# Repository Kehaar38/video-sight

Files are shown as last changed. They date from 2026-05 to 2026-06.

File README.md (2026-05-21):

# VIDEO SIGHT

VIDEO SIGHT is a compact digital sight prototype built around Seeed Studio XIAO ESP32-S3 Sense.

The project goal is a low-latency, approximately 1x-feeling video sight with camera input, LCD display, IMU-assisted attitude information, and a lightweight ballistic overlay for airsoft use.

## Current hardware direction

- Main MCU: Seeed Studio XIAO ESP32-S3 Sense
- Camera: XIAO ESP32-S3 Sense camera module
- Display: Waveshare 1.83 inch LCD Rev2 / ST7789P / 240x284
- IMU: BNO055 module
- UI sub-MCU: ATtiny1616
- Battery: protected 18650 cell
- microSD CS: GPIO21 on XIAO ESP32-S3 Sense
- Peripheral power switch: TPS22919, controlled by D6/GPIO43
- Reverse polarity protection: AO3401A P-MOSFET

## Repository layout

```text
docs/
  hardware/
    parts_and_pinout.md
    power/
    reviews/
hardware/
  kicad/
firmware/
  esp32s3/
  attiny1616/
```

## Status

Early hardware design. The current focus is the power path and first test PCB.

See:

- `docs/hardware/parts_and_pinout.md`
- `docs/hardware/power/power_bom.md`
- `docs/hardware/power/power_design_notes.md`
- `docs/hardware/reviews/2026-05-20_power_schematic_review.md`

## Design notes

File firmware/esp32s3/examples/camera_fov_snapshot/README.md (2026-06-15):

# camera_fov_snapshot

XIAO ESP32S3 Sense付属OV3660カメラのFOV確認用PlatformIO例です。

## 目的

- LCDへライブビューを表示する。
- Wakeボタン(D0/GPIO1)で、カメラ取得フレームをmicroSDへBMP保存する。
- 既知寸法物を撮影し、保存BMP上のピクセル数からカメラFOVを測定する。

## 現在の確認済み設定

```text
Camera: OV3660 / RGB565
Frame: XGA 1024x768
LCD: Waveshare 1.83inch Rev2 / ST7789P / 240x284 / rotation 0
LCD live crop: center 101x118 -> 240x284
SD CS: GPIO21
Wake button: D0/GPIO1 active LOW
```

XGA設定は実機で映像表示できた設定です。QXGA/UXGA RGB565はビルドは通りましたが、実機では `capture failed` になりました。

## FOV測定メモ

VGA保存BMPでの実測値:

```text
測定対象: 150 x 300mmの差し金
距離: カメラから約1000mm
保存画像: 640 x 480px
測定対象の画像上サイズ: 48 x 95px

カメラ生FOV:
  水平: 約90.00°
  垂直: 約74.32°
```

XGA設定では、VGAより高いピクセル密度で再測定できる可能性があります。センサー側クロップ/ROI取得が成功した場合は、その方式をこのFOV測定例にも応用し、LCD表示範囲または指定ROIだけを保存する方向を検討します。

## 使い方

```bash
cd firmware/esp32s3/examples/camera_fov_snapshot
pio run
pio run -t upload
pio device monitor
```

microSDの `/fov/` 配下にBMPが保存されます。

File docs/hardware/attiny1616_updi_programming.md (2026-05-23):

# ATtiny1616 UPDI programming power notes

## Question

A simple 3-pin UPDI header was considered:

```text
1: PERIPH_3V3
2: GND
3: PA0 / UPDI
```

Concern: if a programmer supplies VCC on pin 1, the programmer will energize the entire `PERIPH_3V3` rail, including other peripherals and the TPS22919 OUT side.

## Judgment

That concern is valid.

Do not treat the UPDI header VCC pin as an unconditional external power input for the ATtiny1616 while it is directly tied to `PERIPH_3V3`.

If the programmer drives VCC into this pin, it can power:

- ATtiny1616,
- BNO055 module,
- LCD VCC side,
- any pull-ups/loads on `PERIPH_3V3`,
- TPS22919 VOUT side.

This may also create unwanted reverse/back-power conditions toward the TPS22919 input side depending on the load-switch behavior and surrounding circuitry.

## Recommended approaches

### Preferred: target-powered UPDI header

Use the header VCC pin as target voltage reference/sense only, not as programmer-supplied power.

```text
UPDI header:
  VREF = PERIPH_3V3
  GND
  UPDI = PA0
```

Programming procedure:

1. Power the board normally.
2. Ensure `PERIPH_3V3` is ON.
3. Programmer uses VREF to set 3.3V signal level.
4. Programmer does not source power into VREF.

This is cleanest for in-circuit programming.

### Add a manual PERIPH_EN force option

Because ATtiny1616 is behind TPS22919, it is not powered unless `PERIPH_3V3` is enabled. Add a temporary/jumper option for bring-up:

```text
PERIPH_EN_FORCE:
  PERIPH_EN -> 3.3V through jumper or 10k
```

This lets the rail turn on during programming even before firmware controls GPIO41 correctly.

### If programmer-powered standalone programming is needed

Add an isolation jumper for ATtiny VCC:

```text
PERIPH_3V3 -- JP_ATtiny_VCC -- ATtiny VCC
UPDI_VCC   -- optional programmer VCC input
```

Normal use:

```text
JP_ATtiny_VCC closed
UPDI_VCC not used as power
```

Standalone programming:

```text
JP_ATtiny_VCC open
programmer powers only ATtiny VCC island
```

This is more flexible but adds complexity and another jumper to manage.

## Small implementation notes

- Add a 470Ω〜1kΩ series resistor on the UPDI signal if desired for protection/debug friendliness.
- Label the header clearly: `VREF / GND / UPDI`, not just `VCC / GND / UPDI`, if the pin is not meant to power the rail.
- If using a programmer that always sources VCC, do not connect its VCC pin to `PERIPH_3V3` unless intentionally powering the whole peripheral rail.

## Current recommendation for VIDEO SIGHT test board

Use target-powered UPDI:

```text
J_UPDI:
  1: PERIPH_3V3 as VREF only
  2: GND
  3: PA0/UPDI
```

Also add a jumper/test option to force `PERIPH_EN` high for bring-up/programming.

If later standalone ATtiny programming becomes necessary, add an ATtiny VCC isolation jumper in the second board revision.

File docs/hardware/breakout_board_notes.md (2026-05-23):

# XIAO breakout board notes

## Purpose

Use a small breakout/interposer board and cable between the XIAO ESP32-S3 Sense and the VIDEO SIGHT test board so the XIAO/camera position can be adjusted inside a temporary enclosure.

## BAT- and GND

For the XIAO ESP32-S3 Sense battery connector, `BAT-` should be treated as board `GND`.

Design implication:

- `BAT-` and `GND` can be one schematic net.
- A connector does not need separate logical nets for `BAT-` and `GND`.
- Do not use `BAT-` as an isolated low-side current-sense or low-side switch node; it is not isolated from system ground on the XIAO.

## Cable recommendation

Even though `BAT-` and `GND` are the same logical net, the cable should provide enough ground conductors for return current and signal integrity.

Recommended for the XIAO breakout cable:

- At least one ground conductor paired with the battery/supply path.
- Additional GND pins near SPI/I2C/high-speed/control signal groups if connector pin count allows.
- Prefer not to rely on a single thin GND wire for all XIAO current plus SPI/LCD return current.

Use a single `GND` net in KiCad, but expose multiple physical GND pins on the breakout connector if practical.

## Measurement note

Keep current measurement on the high side as already planned:

```text
18650+ -> SW -> AO3401A -> JP_BAT_CURRENT -> XIAO BAT+
```

Avoid low-side current measurement between `BAT-` and `GND`, because those are common on the XIAO side.

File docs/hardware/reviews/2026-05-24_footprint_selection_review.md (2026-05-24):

# Footprint selection review 2026-05-24

## Scope

Reviewed pushed commit `3e11275` after footprint selection for the VIDEO SIGHT test-board schematic.

KiCad CLI is not available in this environment, so this review is based on the `.kicad_sch` text and project files rather than a full ERC/DRC run.

## Overall judgment

The footprint selection is generally appropriate for a hand-assembled first test board.

Good choices:

- 0805 hand-solder footprints for resistors and small capacitors.
- Large THT test pads for all test points.
- Pin headers for LCD, UPDI, ATtiny breakout, input device, and current/VCC jumpers.
- Keyed IDC 2x10 header for the XIAO breakout cable.
- R7/R8 are now marked DNP in KiCad, matching the schematic note.
- AO3401A uses standard SOT-23 with pin mapping already checked as `1=G, 2=S, 3=D`.

## Selected footprints observed

```text
R1-R8: 0805 hand-solder resistors
C1/C2/C5/C6/C7/C8/C9: 0805 hand-solder capacitors
C3/C4: custom electrolytic/tantalum-style footprint @自分用:CAP_FN_B_PAN
Q1: Package_TO_SOT_SMD:SOT-23
U1: custom @自分用:DCK0006A_L
U2: SOIC-20W 7.5x12.8mm P1.27mm
J1: JST-XH 2-pin vertical
J2: IDC 2x10 P2.54 vertical
J3/J5/J6/J7/J8/JP1/JP2: 2.54mm pin headers
J4: DIP-8 W7.62mm socket footprint for the BNO055 module
SW1: DIP slide switch footprint
SW2-SW5: 6mm THT push buttons
SW6: Alps EC12E vertical encoder
TP1-TP16: THT pad D1.5mm Drill0.7mm
```

## Things that look good

### DNP handling

R7/R8 are now `dnp=yes` in the schematic file. This matches the intended policy:

```text
R7/R8 optional I2C pull-ups
Default: DNP
Populate only if module pull-ups are insufficient
```

### Test points

The selected footprint:

```text
TestPoint:TestPoint_THTPad_D1.5mm_Drill0.7mm
```

is a good default for this test board. It is easy to probe and can accept temporary wires.

### Passive size

0805 hand-solder footprints are a good choice for manual assembly and rework. They are larger than necessary electrically, but well suited for a test board.

### ATtiny package

The SOIC-20W footprint is a friendly choice for hand soldering and recovery compared with smaller packages.

## Items to verify before PCB/order

### 1. Custom footprints must be committed or replaced

The schematic references custom footprint libraries:

```text
@自分用:CAP_FN_B_PAN
@自分用:DCK0006A_L
```

No project `fp-lib-table` or `.pretty` directory was found in the repository. If those footprints exist only in the local KiCad user library, another machine or CI will not be able to resolve them.

Recommended options:

1. Commit the custom `.pretty` library and project `fp-lib-table`, or
2. Replace with standard KiCad footprints if suitable.

This is especially important for `U1` / TPS22919, because the exact DCK/SOT-563-style pad geometry matters.

### 2. TPS22919 footprint/pin mapping

`U1` uses:

```text
@自分用:DCK0006A_L
```

Before layout/order, verify against the TPS22919 datasheet:

- pin 1 location,
- pad numbering,
- package variant DCK,
- thermal/assembly recommendations,
- KiCad symbol pin numbers.

### 3. C3/C4 footprint and polarity

C3/C4 are both `47uF` and use the custom `CAP_FN_B_PAN` footprint.

Check:

- capacitor type: electrolytic, tantalum, polymer, or large MLCC,
- polarity marking if polarized,
- voltage rating,
- physical height/diameter,
- pad spacing and courtyard.

If using polarized capacitors, make polarity very clear on silkscreen.

### 4. BNO055 module socket footprint

`J4` uses:

```text
Package_DIP:DIP-8_W7.62mm_Socket
```

This can work if the module header really matches 2x4, 2.54mm pitch, 7.62mm row spacing. Before PCB order, measure/check the AE-BNO055-BO board header spacing.

A generic `PinSocket_2x04_P2.54mm` footprint may be clearer than a DIP IC socket footprint if the physical part is a module header/socket.

### 5. IDC connector orientation

`J2` uses:

```text
Connector_IDC:IDC-Header_2x10_P2.54mm_Vertical
```

This matches the keyed-cable plan. Still verify in PCB:

- pin 1 mark,
- key notch direction,
- cable exits in the intended direction,
- straight-through cable maps J1 pin N to J2 pin N,
- no mirrored orientation between breakout and test board.

### 6. LCD header mechanical fit

`J3` is a normal 1x08 vertical pin header. Confirm this matches the Waveshare module orientation and whether the module should plug directly, use wires, or use a socket.

### 7. Switch and encoder footprints

The selected footprints are plausible, but they depend heavily on exact parts:

- `SW_PUSH_6mm` for tactile switches,
- `RotaryEncoder_Alps_EC12E_Vertical_H20mm` for encoder,
- DIP slide switch footprint for SW1.

Before ordering, compare to the actual part datasheets or the parts in hand.

## User follow-up decisions

After this review, the following project decisions were noted:

- The custom footprints were downloaded from public sources. The repository is public, but third-party reuse is not a major goal for this project.
- TPS22919, C3/C4, and BNO055 footprints were chosen based on actual parts/modules in hand, so mechanical fit is expected to be acceptable.
- The IDC cable will be obtained before PCB order so the key orientation and straight-through pin mapping can be checked physically.
- The bundled LCD cable terminates in a normal 2.54mm pin socket and can be reversed. For the final build, consider making a custom cable or keyed connection that fixes orientation.

## Custom-footprint policy note

If the downloaded footprints have a license that allows redistribution, committing a project-local `.pretty` library is ideal.

If the license is unclear or redistribution is inconvenient, it is acceptable for this personal/prototype repository to keep them as local KiCad user-library footprints, but then the project is not fully reproducible from Git alone.

For this project, the practical minimum is:

- keep the exact source URL/package name for each custom footprint in a note,
- export Gerbers from the same KiCad environment that has those footprints installed,
- visually inspect the generated Gerber/pads before ordering.

## Summary

Accepted as a test-board footprint baseline:

- 0805 hand-solder passives,
- THT test points,
- pin headers/jumpers,
- SOIC-20W ATtiny,
- SOT-23 AO3401A,
- DNP status for R7/R8.

Main reproducibility caveat:

- custom footprints `@自分用:*` are local unless their source/license allows committing them or they are replaced by standard/library footprints.

Main mechanical checks before PCB order:

- TPS22919 DCK footprint pin mapping,
- BNO055 module row spacing,
- IDC key orientation using the actual cable,
- LCD cable/header orientation or custom keyed cable plan,
- switch/encoder exact part footprints.

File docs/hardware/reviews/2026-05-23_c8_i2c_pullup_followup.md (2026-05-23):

# Schematic review follow-up 2026-05-23: C8 and I2C pull-ups

## Scope

Reviewed pushed update `367950b`:

- moved C8 around the ATtiny1616 VCC jumper,
- added board-side I2C pull-up resistors R7/R8,
- checked the AE-BNO055-BO module documentation image.

## ATtiny1616 C8

C8 is now on the `UPDI_VCC` / ATtiny VCC side of JP2:

```text
PERIPH_3V3 -- JP2 -- UPDI_VCC / ATtiny VCC
                         |
                        C8 0.1uF
                         |
                        GND
```

This is the correct side for the MCU local decoupling capacitor. It will still decouple the ATtiny when JP2 is open and the programmer powers `UPDI_VCC` directly.

## Board-side I2C pull-ups

The added topology is correct:

```text
PERIPH_3V3
  ├─ R7 4.7k -> I2C_SDA
  └─ R8 4.7k -> I2C_SCL
```

Pulling SDA/SCL to `PERIPH_3V3` is the right rail because BNO055 and ATtiny1616 are on the switched peripheral 3.3V domain.

## AE-BNO055-BO module pull-ups

The provided module documentation appears to show pull-up resistors already present on the module:

- parts list: `R1-R5 = RK73B1ETTP103J`, where `103` means 10kΩ,
- schematic: R1/R2 appear associated with the I2C signal lines and the module's 2.8V domain.

So the module may already provide I2C pull-ups, likely around 10kΩ. The board-side 4.7k pull-ups are therefore best treated as optional/DNP until measured or confirmed.

## Electrical implication if both are populated

If the module has 10k pull-ups and the board also installs 4.7k pull-ups, the effective pull-up becomes stronger:

```text
4.7k || 10k ≈ 3.2kΩ
```

That is usually acceptable for a short 3.3V I2C bus.

If the module pull-ups are to 2.8V while the board pull-ups are to 3.3V, the idle level becomes a weighted value, roughly around 3.1V with 10k-to-2.8V and 4.7k-to-3.3V. This is probably still recognized as High by 3.3V devices, but mixing pull-up rails is not as clean as using one defined pull-up rail.

## Recommendation

For the test board:

- Keep R7/R8 footprints.
- Mark R7/R8 as DNP by default, or choose footprints that are easy to leave open/populate later.
- During bring-up, first measure SDA/SCL idle voltage with the BNO055 module installed and R7/R8 unpopulated.
- If idle level/rise time is weak, populate R7/R8.

Suggested schematic note:

```text
R7/R8: optional I2C pull-ups to PERIPH_3V3; DNP if BNO055 module pull-ups are sufficient.
```

## Summary

Accepted:

- C8 placement is now correct.
- R7/R8 topology is correct for board-side optional I2C pull-ups.

Recommended change before layout/BOM:

- Make R7/R8 optional/DNP by default or add a note, because the AE-BNO055-BO module likely already includes 10k I2C pull-ups.

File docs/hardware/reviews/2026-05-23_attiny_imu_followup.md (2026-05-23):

# Schematic review follow-up 2026-05-23: ATtiny UPDI and IMU updates

## Scope

Reviewed pushed updates after:

- adding ATtiny1616 UPDI/programming VCC selection,
- adding the internal-pull-up note for the input devices,
- adding IMU test points,
- marking unused XIAO breakout camera I2C lines as NC.

## ATtiny1616 / UPDI

The jumper-based VCC selection is the right direction.

Current visible intent:

```text
PERIPH_3V3 -- JP2 ATTINY_VCC -- UPDI_VCC / ATtiny VCC
J4:
  pin 1 = UPDI_VCC
  pin 2 = GND
  pin 3 = PA0_UPDI through R6 470Ω
```

This lets the ATtiny be normally powered from `PERIPH_3V3`, while allowing the ATtiny-side VCC node to be separated for programmer-powered work.

### Important check: decoupling capacitor location

In the screenshot, C8 appears to be on the `PERIPH_3V3` side of JP2. If JP2 is open and the programmer powers `UPDI_VCC`, C8 may no longer decouple the ATtiny VCC pin.

Recommendation:

- Put the ATtiny local 0.1µF decoupling capacitor on the ATtiny VCC / `UPDI_VCC` side, as close to U3 VCC/GND as practical.
- If desired, keep an additional capacitor on `PERIPH_3V3`, but the mandatory MCU decoupling should follow the MCU VCC island.

### Labeling recommendation

Add a note near JP2/J4 such as:

```text
Normal: JP2 closed, UPDI_VCC = PERIPH_3V3, programmer VCC as VREF only
Programmer-powered: JP2 open, programmer may power UPDI_VCC only
```

This prevents accidentally powering the whole `PERIPH_3V3` rail from the UPDI programmer.

### UPDI series resistor

R6 = 470Ω on PA0_UPDI is good for a test board. It adds some protection/debug friendliness without being excessive.

### Input pull-up note

The input-device note `ATtiny internal pull-up enabled` is good. The switch/encoder wiring to GND is consistent with firmware-enabled internal pull-ups.

## IMU / BNO055

The IMU update added test points, not I2C pull-ups. The visible support pins are now brought to test points:

```text
TP13 = IMU_2V8
TP14 = GND
TP15 = IMU_INT
TP16 = IMU_RESET
```

This is useful for bring-up.

### I2C pull-ups still remain as a separate future check

Because the IMU change was TP-only, discrete I2C pull-up resistors are still a separate design decision. The screenshot and KiCad text currently do not show board-side pull-up resistors such as:

```text
I2C_SDA -> 4.7k -> PERIPH_3V3
I2C_SCL -> 4.7k -> PERIPH_3V3
```

If the intended pull-ups are on the BNO055 module, that may be acceptable. If the intent was to add optional board-side pull-up footprints, they do not appear to be present in the pushed schematic yet.

Recommendation for test board:

- Add optional/DNP board-side pull-up footprints on SDA/SCL to `PERIPH_3V3`, or
- Add a note that the pull-ups are supplied by the BNO055 module.

### IMU_2V8 caution

Keeping `IMU_2V8` as a test point is fine. Treat it as a module-side output/reference unless the exact module documentation says otherwise. Do not connect it to `PERIPH_3V3`.

## CAM_SDA / CAM_SCL

Marking unused `CAM_SDA` and `CAM_SCL` as NC is good if they are not routed to test points or used on the test board.

## Summary

Accepted:

- VCC jumper approach for ATtiny programming,
- 470Ω UPDI series resistor,
- internal pull-up note for input devices,
- IMU support/test points,
- CAM_SDA/CAM_SCL NC marking.

Still separate future check:

- optional I2C pull-up resistors or a note that module-side pull-ups are used.

1. Move/add the ATtiny 0.1µF decoupling capacitor to the `UPDI_VCC` / ATtiny VCC side of JP2.
2. Add a clear JP2/J4 programming-power note.
3. Confirm whether I2C pull-ups are module-provided or add optional DNP 4.7k pull-ups to `PERIPH_3V3`.

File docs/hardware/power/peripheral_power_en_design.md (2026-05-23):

# VIDEO SIGHT 周辺電源EN案

## 対象

DeepSleep時に電源を落とす対象は、XIAO 3V3ピンから供給予定だった外部周辺のみ。

- Waveshare 1.83inch LCD Rev2 VCC
- BNO055 VCC
- ATtiny1616 VCC

XIAO本体、Senseカメラ、microSD等の基板内蔵系はこのENでは制御しない。

## 現在の方針

- `PERIPH_3V3` はTPS22919ロードスイッチで作る。
- `PERIPH_EN` は GPIO41 / D12 背面パッドから制御する。
- D6 / GPIO43 は `LCD_BL` に戻し、LCDバックライトPWM調光用として使う。
- ENには100kΩ程度のプルダウンを入れ、起動直後/DeepSleep中/リセット中に周辺電源がOFFになるようにする。

## 評価

利点:

- D6/GPIO43をLCD_BLに戻せるため、バックライト電流と輝度を実測・調整できる。
- LCD/IMU/サブMCUをDeepSleep時に確実に落とせる。
- GPIOがHi-ZになってもプルダウンでOFFにできる。
- 周辺電源制御が1本にまとまり、ソフト電源ボタン設計と相性がよい。

注意点:

- GPIO41/D12はXIAO背面パッド側なので、ブレイクアウトボードで確実に引き出す必要がある。
- XIAOのカメラシールド/マイク用ジャンパーとの関係を確認する。
- 周辺電源OFF中にSPI/I2C/GPIOからバックパワーしないよう、DeepSleep前に信号線をLow/Hi-Zへ落とす。
- ATtiny1616も電源OFFになるため、UIサブMCUでWakeする構成ではなく、XIAO直結Wakeボタンで復帰する。

## 推奨回路イメージ

```text
XIAO_3V3
  ↓
TPS22919 Load Switch
  EN ← GPIO41 / D12 pad + pulldown
  ↓
PERIPH_3V3
  ├─ LCD VCC
  ├─ BNO055 VCC
  └─ ATtiny1616 VCC

D6 / GPIO43
  ↓
LCD_BL
```

## 追加確認

- ロードスイッチの入力電圧範囲: 3.3V対応。
- 出力電流: LCD/IMU/ATtinyの合計電流に十分余裕。
- R_on: 電圧降下が小さいもの。
- EN閾値: ESP32の3.3V GPIOで確実にON/OFFできる。
- OFF時リーク電流: DeepSleep目標に合う。
- 起動順: 起動後にGPIO41を出力Low→周辺初期化直前にHigh。

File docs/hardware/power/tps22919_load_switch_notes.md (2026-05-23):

# TPS22919 検討メモ

## 用途

VIDEO SIGHT の `PERIPH_3V3` 生成用ロードスイッチ候補。

```text
XIAO 3V3
  → TPS22919
  → PERIPH_3V3
      - LCD VCC
      - BNO055 VCC
      - ATtiny1616 VCC
```

LCD_BLはD6/GPIO43で別制御する。

ENは GPIO41/D12 pad から制御し、ENにプルダウンを入れて起動直後/DeepSleep中はOFFへ倒す。

## 確認した仕様

TI製品ページより:

- 品名: TPS22919
- 機能: 5.5-V, 1.5-A, 90-mΩ load switch with adjustable output discharge
- Vin: 1.6V〜5.5V
- Imax: 1.5A
- Ron typ: 90mΩ
- Iq typ: 8µA
- Shutdown current typ: 0.002µA
- Features: Inrush current control, Quick output discharge, Short circuit protection, Thermal shutdown
- Soft start: Fixed rise time
- Package image: 6-pin DCK

DCKはTIの小型リード付きSMDパッケージ系で、QFN/BGAではない。手はんだは可能だがかなり小さい。

## 電圧降下・発熱目安

Ron=90mΩとして:

- 0.1A: 9mV / 0.9mW
- 0.2A: 18mV / 3.6mW
- 0.3A: 27mV / 8.1mW
- 0.5A: 45mV / 22.5mW
- 1.0A: 90mV / 90mW
- 1.5A: 135mV / 202.5mW

VIDEO SIGHTの周辺電流が数十〜数百mAなら十分余裕がある。

## 判断

TPS22919はVIDEO SIGHTの周辺電源スイッチとして使える。保護機能と低Ron、低シャットダウン電流があり、3.3Vロードスイッチ用途に合う。

注意:

- パッケージDCKはリード付きだが小さい。試作ではDCK→DIP変換基板等を使うとよい。
- ENピンには外付けプルダウンを入れる。
- Quick output discharge付きなので、OFF時にPERIPH_3V3が速く落ちる。LCD/IMU/ATtiny用途には都合が良い。
- 出力側大容量コンデンサやバックライト突入電流はデータシート推奨に従って確認する。

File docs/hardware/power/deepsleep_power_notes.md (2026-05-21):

# XIAO ESP32-S3 Sense DeepSleep と周辺電源メモ

## 調査元

- Seeed Studio Wiki: `XIAO ESP32S3 Sense Sleep Modes`
- Espressif ESP-IDF Programming Guide: ESP32-S3 Sleep Modes
- Seeed Studio Wiki: XIAO ESP32-S3 pin multiplexing / 3V3説明

## 結論

- XIAOの3V3端子は、オンボードDCDCレギュレータの出力であり、DeepSleepに入っても自動的に切れるものではないと考える。
- ESP32-S3のDeepSleepでは、CPU、ほとんどのRAM、APB_CLK系のデジタル周辺は電源断/停止する。
- 通常GPIOの出力状態は、DeepSleep中に通常動作時と同じように能動駆動される前提にしない。
- RTC GPIOやGPIO hold機能で一部状態保持は可能だが、VIDEO SIGHTでは「GPIO状態に頼って周辺電源が勝手に落ちる」と考えない方が安全。

## VIDEO SIGHTでの設計判断

- 周辺機器をDeepSleep中に落としたい場合は、3V3直結ではなく、ロードスイッチまたはP-MOSFET高側スイッチ等で周辺電源レールを作る。
- 周辺電源ENは、ESP32が起きている時だけONになる設計にする。
- ESP32がDeepSleepに入りGPIOがHi-Z/未保持になっても、抵抗でENがOFF側へ倒れるようにする。
- 周辺電源OFF中は、SPI/I2C/GPIOからバックパワーしないように、DeepSleep直前に関連GPIOをLowまたはHi-Zへ設定する。
- 物理電源スイッチはバッテリーとXIAO BATを切断する形でよい。この場合、切断中はUSB充電不可。保管/バッテリー交換用の完全OFFとして扱い、使用中の一時停止はDeepSleepに任せる。

## 推奨電源ブロック

```text
保護回路付き18650
  ↓
P-MOSFET逆接保護
  ↓
物理電源スイッチ
  ↓
XIAO BAT
  ↓
XIAO 3V3
  ├─ XIAO本体/カメラ系
  └─ 周辺電源ロードスイッチ
       ├─ LCD VCC / BL系
       ├─ BNO055
       └─ ATtiny1616
```

※ カメラ/Sense拡張基板側の電源がXIAO内部でどう分かれているかは、実機でDeepSleep時電流を測る。

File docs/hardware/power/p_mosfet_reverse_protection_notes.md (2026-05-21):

# VIDEO SIGHT P-MOSFET逆接保護メモ

## 選定条件

1セルLi-ion/18650の入口逆接保護用。

- P-channel MOSFET
- VDS定格: 20V以上あれば十分、30V品なら余裕
- RDS(on): VGS=-2.5Vまたは-4.5Vで低いこと。目安100mΩ以下、できれば70mΩ以下
- ID: 連続1A以上、できれば2〜3A級
- VGS(max): ±12Vまたは±20V。1セルLi-ionでは通常問題なし
- パッケージ: SOT-23等のリード付きSMDが扱いやすい。真のDIP/TO-92品は低RDS品が少ない

## 定番候補

- AO3401A / 互換品
  - P-ch, 30V, SOT-23系。安価で入手性が高く、1セル機器の逆接保護でよく使われる。
  - クローン/互換品が多いので、可能ならメーカー品または信頼できる販売店から買う。
- IRLML6402
  - P-ch, 20V, SOT-23系。ロジックレベル寄りで低電圧用途に使いやすい。
- DMP3098L
  - Diodes Inc.のP-ch, 30V, SOT-23系。メーカー品として選びやすい。
- DMG2305UX等
  - Diodes Inc.の小型P-ch候補。低RDSで入手できる場合は良い。

## 回路案

物理スイッチOFFで完全に電池を切りたいなら、スイッチはできればP-MOSFET前段に置く。

```text
保護回路付き18650 +
  ↓
物理電源スイッチ
  ↓
P-MOSFET drain
P-MOSFET source
  ↓
XIAO BAT+
```

P-MOSFETのゲートはGNDへ高抵抗で落とす。

```text
Gate ─ 1MΩ程度 ─ GND
```

Li-ion 1セルではVGSが最大でも約-4.2Vなので、通常はゲート保護ツェナーは不要。ただし長い配線や静電気が気になるなら保護部品を検討する。

## 向き

P-MOSFETのボディダイオードが、正しい極性で一瞬だけ入力から出力へ流れる向きにする。

一般的には:

```text
Drain  = バッテリー/スイッチ側
Source = XIAO BAT側
Gate   = GNDへ抵抗
```

正接続時はボディダイオード経由でSource側が上がり、その後 VGS<0 になってMOSFETがONする。逆接続時はボディダイオードが遮断方向になり、負荷側を守る。

## 抵抗値

- Gate-GND: 1MΩ程度を推奨。4.2V時の常時消費は約4.2µA。
- 100kΩでも動作は堅いが、物理OFF時にこの抵抗が電池へ残る配置だと約42µAを消費する。
- 物理スイッチをMOSFET前段に置けば、OFF時はこの消費も切れる。

## 決定

VIDEO SIGHTでは `AO3401A` を採用する。Digi-Keyで購入するため、互換品/クローンではなく信頼できるメーカー品として扱う。

実装方針:

- パッケージはSOT-23想定。
- PCBAは使わず自分ではんだ付けする。
- SOT-23程度は手実装可能な前提。
- 基板はユニバーサル基板ではなくKiCadで設計し、JLCPCBへ発注する。
- まずテスト用の大きめ基板、その後に筐体組み込み用の本番基板の2段階で作る。

注意:

- AO3401AのSOT-23フットプリントはメーカー推奨ランドまたはJLCPCBで一般的なSOT-23-3ランドを使う。
- Drain/Source/Gateのピン番号をKiCadシンボルと実データシートで必ず照合する。
- 逆接保護ではDrain=バッテリー/スイッチ側、Source=XIAO BAT側、Gate=GNDへ抵抗の向きで確認する。

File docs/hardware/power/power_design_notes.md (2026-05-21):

# VIDEO SIGHT 電源設計メモ

## 現在の方針

- セル: 保護回路付き18650。
- 充電: XIAO USB-C経由の低速充電と、セル取り外しによる外部充電器充電の両対応。
- 逆接保護: P-MOSFET方式を盛り込む。
- 測定: 電流測定用のジャンパ/テストポイントを設ける。
- 電源スイッチ: 物理スイッチあり。
- LCDバックライト: 初期試作ではGPIO直結。ただしBL電流は実測し、GPIO定格超過や発熱があればMOSFET駆動へ変更。
- バッテリー電圧測定: 抵抗分圧を常時接続。
- DeepSleep: 周辺機器もオフにする方針。

## 追加で確認する項目

1. 電源経路とスイッチ位置
   - 物理スイッチをBAT+側のどこに入れるか。
   - OFF時にUSB-C充電を許すか、完全に切るか。
   - USB-C給電中/充電中/電池駆動中の3状態で意図しない逆流がないか。

2. P-MOSFET逆接保護
   - ソース/ドレイン向きとボディダイオードの向きを確認。
   - ゲート保護抵抗、ゲート-ソース抵抗を入れる。
   - 使用電流でのRds(on)による電圧降下と発熱を確認。
   - 保護回路付き18650の低電圧時でもXIAO BAT入力に必要電圧が残るか確認。

3. LCDバックライトGPIO直結の安全性
   - Waveshare 1.83inch LCD Rev2のBLピン回路を確認。
   - BLピンがLED直結/抵抗入り/トランジスタ入力のどれかを確認。
   - GPIO電流定格を超える場合はN-MOSFET PWMへ変更。

4. 周辺電源OFF方式
   - LCD、BNO055、ATtiny1616、必要ならSDへの電源をどう切るか。
   - ロードスイッチまたはP-MOSFET高側スイッチを使うか。
   - OFF時にSPI/I2C/GPIOから周辺へバックパワーしないよう、信号線状態を定義する。
   - ATtiny1616をDeepSleep中も生かすか、完全OFFにするかを決める。

5. Wake設計
   - D0/GPIO1 WakeボタンはDeepSleep復帰用。
   - 周辺電源OFF中でもWake回路が有効か確認。
   - RTC wake対応ピン/外部ウェイク方式を実装前に確認。

6. バッテリー分圧
   - 抵抗値、ADC入力電圧範囲、常時消費電流を決める。
   - ADC読み取り用に分圧中点へ小容量コンデンサを入れるか検討。
   - 実測で電圧補正係数を持つ。

7. 3V3レール余裕
   - カメラ表示、LCD最大輝度、SDアクセス、IMU動作時の電圧降下と発熱を測る。
   - XIAOの3V3出力公称700mAに対して実使用ピークを確認する。
   - 3V3入力側/周辺側へ47〜100uF程度のバルク容量を置く。

8. USB-C充電中の熱
   - XIAO充電IC、DCDC、LCDバックライト、筐体内温度を確認。
   - 充電しながら使用する場合と、電源OFF充電の場合を分けて測る。

9. テストポイント
   - BAT+、BAT後段、3V3、GND、LCD_BL、I2C SDA/SCL、SPI SCK/MOSI/MISO、周辺電源ENを出す。
   - 電流測定用にBAT経路または3V3周辺電源経路へジャンパを入れる。

10. ヒューズ/安全部品
   - 保護回路付きセルを使うが、試作配線や筐体内短絡に備えてリセッタブルヒューズや細い保護配線も検討する。

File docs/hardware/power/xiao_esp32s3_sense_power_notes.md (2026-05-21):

# XIAO ESP32-S3 Sense 電源・充電メモ

## 調査元

- Seeed Studio Wiki: Getting Started with Seeed Studio XIAO ESP32-S3 Series
- Seeed Studio Wiki: Pin Multiplexing with Seeed Studio XIAO ESP32-S3 (Sense)
- Seeed Studio公開KiCad/PDF: `202003753_XIAO ESP32S3 Sense_v1.5_SCH_260226`
- SGMICRO product pages: SGM40567, SGM6029

## 確認できた構成

- 充電IC: `SGM40567-4.2XG/TR`
  - 1セルLi-ion/Li-poly系のリニア充電IC。
  - 4.2V版。
  - Seeedの仕様表では、XIAO ESP32-S3 Sense系の充電電流は `100mA(Fast) / 0.9mA(Trickle)` と読める。
  - 充電中/完了表示用の `NCHG` ピンがCHARGE LEDへ接続されている。
- 3.3Vレギュレータ: `SGM6029CYG/TR`
  - SGM6029は同期整流降圧DCDC。
  - SGMICROページでは入力1.95V〜5.5V、低消費、0.6A〜1A級ピーク出力電流とされる。
  - XIAO pin multiplexingページでは3V3ピンから `700mA` 取り出し可能と記載。
- BAT端子: `VBAT`ネット。
  - 3.7V Li-ion/Li-polyセル接続想定。

## 保護機能について

- `SGM40567` は充電管理ICであり、データシート/製品ページ上は充電制御、再充電、トリクル/プリチャージ、熱電流制限などの機能を持つ。
- ただし、XIAO Sense回路中に `DW01`, `FS8205` 等の典型的な1セルLi-ion保護IC/保護FETは確認できなかった。
- したがって、XIAO側だけにセル保護を任せる前提は避ける。過放電・過電流・短絡保護付きセルまたは外部保護基板付き18650を使うのが安全。

## VIDEO SIGHTへの設計上の意味

- 18650は保護回路付き、または保護基板付きホルダーを推奨。
- 充電電流は大きくないため、USB-C充電は可能だが高速充電用途ではない。
- 3V3レールは公称700mAまで使えるとされるが、カメラ+LCD+IMU+ATtiny+SDを載せるため、実測で電圧降下と発熱を確認する。
- LCDバックライトはできればMOSFETでPWM駆動し、3V3レールの余裕と発熱を確認する。
- USB給電中の動作・充電同時運用は発熱確認が必要。

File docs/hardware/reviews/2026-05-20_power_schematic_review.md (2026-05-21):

# VIDEO SIGHT schematic review 2026-05-20 power draft

## Reviewed images

- XIAO ESP32-S3 Sense symbol / main power nets
- 18650 + SW + AO3401A reverse protection
- Battery divider
- TPS22919 peripheral load switch

## Findings

### OK: AO3401A reverse protection

Current schematic shows:

```text
18650+ → SW → AO3401A pin3
AO3401A pin2 → +BATT
AO3401A pin1 → 1MΩ → GND
```

This matches the intended direction if the KiCad AO3401A symbol uses common pinout:

- pin1 = Gate
- pin2 = Source
- pin3 = Drain

Action: verify against the exact Digi-Key/AOSMD AO3401A datasheet and footprint before PCB.

### OK: Battery divider

Current schematic:

```text
+BATT → 470kΩ → ADC node → 220kΩ → GND
ADC node → 0.047µF → GND
```

This is good. `+BATT` must mean the protected/switched node after AO3401A, not raw battery.

Calculation:

- 4.2V → about 1.34V at ADC
- divider current at 4.2V → about 6.1µA
- Rth ≈ 150kΩ, C=0.047µF gives τ≈7ms, 5τ≈35ms

### Important: TPS22919 output net name

The TPS22919 output is currently shown with a `+3V3` power symbol. This is dangerous/confusing because KiCad power symbols are global. If any other `+3V3` appears on the unswitched XIAO 3V3 rail, it will short TPS22919 IN and OUT and bypass the load switch.

Action: rename nets:

```text
XIAO 3V3 pin / TPS IN  = XIAO_3V3 or 3V3_RAW
TPS OUT                = PERIPH_3V3
```

Do not use the same global `+3V3` symbol on both sides of TPS22919.

### OK: TPS22919 EN pulldown

`EN → 100kΩ → GND` is good. D6/GPIO43 drives the same EN net.

### QOD / R_QOD

TPS22919 QOD is optional but useful.

Datasheet behavior:

- QOD open: output discharge disabled.
- QOD tied to OUT directly: fastest discharge through internal QOD path, about 24Ω typ internal resistance.
- QOD tied to OUT through external R_QOD: adjustable/slower output discharge.

For VIDEO SIGHT, using QOD is recommended so `PERIPH_3V3` collapses reliably before DeepSleep.

Suggested population options:

- R_QOD = 0Ω: fastest discharge. With about 48µF output capacitance, initial discharge current roughly 3.3V/24Ω ≈ 137mA, τ≈1.2ms.
- R_QOD = 100Ω: gentler, initial roughly 27mA, 5τ≈30ms for 48µF.
- R_QOD = 1kΩ: very gentle, initial roughly 3.2mA, 5τ≈250ms for 48µF.
- DNP/open: disables QOD; not preferred if peripherals need clean power reset.

Recommendation: place R_QOD footprint. For first test, populate 100Ω or 1kΩ. Use 0Ω if fast discharge/reset is needed.

### Missing later, expected

- Current measurement jumper(s)
- Battery holder footprint
- Test points
- PERIPH_3V3 bulk capacitor if not on another sheet
- Local decoupling for LCD/IMU/ATtiny modules

## Summary

No fatal issue in the shown draft, but change TPS22919 OUT from global `+3V3` to a distinct `PERIPH_3V3` net before continuing. Keep R_QOD footprint; it is optional electrically, but useful for controlled shutdown.

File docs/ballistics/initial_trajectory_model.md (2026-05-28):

# 初期弾道予測モデル

## 目的

VIDEO SIGHTの初期弾道予測モデルは、実射精度を最初から追い込むための物理シミュレーターではなく、次の機能を先に成立させるための表示用モデルである。

```text
- 固定値から弾道点を計算できる
- LCDへ弾道点をプロットできる
- IMU由来のpitch/rollで表示が変化する
- ハードウェア、描画、IMU、UIの開発を進められる
```

この段階では、風、地面、yaw、射撃中の姿勢変化、実射補正、回転減衰、揚力/抗力係数の変化は扱わない。

## モデルの考え方

このモデルでは、世界座標を明示的に持たない。弾道は、照準器/カメラに固定された `f/r/u` 座標の中で計算する。

```text
f: forward / カメラ前方 / 銃口方向
r: right   / 画面右方向
u: up      / 画面上方向 / ホップ揚力の基準方向
```

弾道予測は「今の姿勢で撃った場合に、カメラ画面内で弾道点がどこへ出るか」を求めるものとする。

そのため、次のものは考慮しない。

```text
風向き:
  測れないため考慮しない。

地面に対するターゲット位置:
  ターゲットはf方向距離だけで扱う。

射撃中の姿勢変化:
  今時点の姿勢での予測表示のみ扱う。

方位/yawを含む空間位置:
  カメラから覗く世界だけを扱うため考慮しない。

地面:
  地形や設置物により一定の地面を仮定できないため、モデルには入れない。
```

## 初期固定値

初期段階では、弾・銃・空気・ホップ関連の値を固定する。

```text
BB重量: 0.20 g
BB直径: 6.0 mm
初速: 90 m/s
空気密度: 1.225 kg/m^3
抗力係数 C_D: 0.47
マグヌス係数 C_L: 0.038
最大予測距離: 40 m
距離ステップ: 2 m
プロット点数: 21点
ゼロイン距離: 30 m相当
サイト高: 仮値 0.05 m
```

計算用の値:

```text
m   = 0.0002 kg
rBB = 0.003 m
A   = π × rBB²
ρ   = 1.225 kg/m^3
Cd  = 0.47
Cl  = 0.038
g   = 9.80665 m/s^2
v0  = 90.0 m/s
```

断面積:

```text
A = π × 0.003²
  ≒ 2.8274e-5 m²
```

抗力・揚力用の定数:

```text
K_drag = 0.5 × ρ × A × Cd / m
K_lift = 0.5 × ρ × A × Cl / m
```

上記固定値では:

```text
K_drag ≒ 0.04070
K_lift ≒ 0.00329
```

## IMUから使う値

初期段階では、IMUから次の2値だけを使う。

```text
pitch = θ
roll  = φ
```

単位はラジアンとする。

```text
pitch θ > 0:
  銃口を上へ向ける。

roll φ > 0:
  銃を右へ倒す。
```

`yaw` は使わない。BNO055のyawは磁気環境の影響を受けやすく、VIDEO SIGHTの初期表示では必要ないため。

## 状態量

弾の位置と速度は `f/r/u` 成分で持つ。

```text
位置:
  p = (pf, pr, pu)

速度:
  v = (vf, vr, vu)
```

初期値:

```text
pf = 0
pr = 0
pu = 0

vf = v0
vr = 0
vu = 0
```

つまり、初速方向は常に `+f` とする。

## 重力

世界座標は持たないが、重力が現在の `f/r/u` 座標でどの方向に見えるかをpitch/rollから分解する。

```text
g_f = -g × sinθ
g_r =  g × cosθ × sinφ
g_u = -g × cosθ × cosφ
```

例:

```text
水平・ロールなし:
  pitch = 0°
  roll  = 0°

  g_f = 0
  g_r = 0
  g_u = -g

  → 画面下方向へ落ちる。
```

```text
真上に向ける:
  pitch = 90°

  g_f = -g
  g_r = 0
  g_u = 0

  → 前進方向に逆らう。
```

```text
水平・右90度ロール:
  pitch = 0°
  roll  = 90°

  g_f = 0
  g_r = +g
  g_u = 0

  → 画面右方向へ落ちる。
```

## 抗力

抗力は速度ベクトルと逆向きに計算する。

速度の大きさ:

```text
speed = sqrt(vf² + vr² + vu²)
```

抗力:

```text
a_drag = -K_drag × speed × v
```

成分:

```text
a_drag_f = -K_drag × speed × vf
a_drag_r = -K_drag × speed × vr
a_drag_u = -K_drag × speed × vu
```

## マグヌス揚力

ホップ揚力の基準方向は `+u` とする。ただし、揚力は速度に対して垂直に働くものとして、`+u` から速度方向成分を取り除く。

速度単位ベクトル:

```text
v_hat = v / speed
```

基準上方向:

```text
u_axis = (0, 0, 1)
```

`u_axis` から速度方向成分を除去する。

```text
lift_dir = u_axis - dot(u_axis, v_hat) × v_hat
lift_dir = normalize(lift_dir)
```

揚力:

```text
a_lift = K_lift × speed² × lift_dir
```

成分:

```text
a_lift_f = K_lift × speed² × lift_dir_f
a_lift_r = K_lift × speed² × lift_dir_r
a_lift_u = K_lift × speed² × lift_dir_u
```

これにより、ホップ揚力は画面上方向を基準にしつつ、弾の実際の速度方向に対して垂直になる。

## 合計加速度

```text
a_f = a_drag_f + a_lift_f + g_f
a_r = a_drag_r + a_lift_r + g_r
a_u = a_drag_u + a_lift_u + g_u
```

## 数値積分

時間刻み `dt` で速度と位置を更新する。

```text
vf += a_f × dt
vr += a_r × dt
vu += a_u × dt

pf += vf × dt
pr += vr × dt
pu += vu × dt
```

`dt` はまず次を使う。

```text
dt = 0.001 s
```

必要に応じて、見た目や安定性確認用に次へ小さくしてよい。

```text
dt = 0.0005 s
```

## nメートル先の点を取る

距離は `f` 方向距離だけを扱う。

```text
pf >= target_distance_m
```

になったところを、nメートル先の点とする。

より滑らかにするため、前ステップとの線形補間を行う。

```text
alpha = (target_distance_m - pf_prev) / (pf - pf_prev)

pr_n = pr_prev + alpha × (pr - pr_prev)
pu_n = pu_prev + alpha × (pu - pu_prev)
```

画面上の変位:

```text
screen_x_m = pr_n
screen_y_m = pu_n
```

意味:

```text
screen_x_m:
  照準中心から右方向へのズレ[m]

screen_y_m:
  照準中心から上方向へのズレ[m]
```

## LCD座標への変換

最初は単純なスケールでよい。

```text
px = center_x + screen_x_m × scale
py = center_y - screen_y_m × scale
```

LCD座標は下方向が正なので、`screen_y_m` は符号を反転して使う。

カメラ視野角に合わせる段階では、角度ベースにする。

```text
angle_x = atan2(screen_x_m, target_distance_m)
angle_y = atan2(screen_y_m, target_distance_m)

px = center_x + fx_px × tan(angle_x)
py = center_y - fy_px × tan(angle_y)
```

初期の見た目確認では、単純スケールで十分とする。

## C風擬似コード

```c
// f/r/u frame
// p = (pf, pr, pu)
// v = (vf, vr, vu)

float theta = pitch_rad;
float phi   = roll_rad;

// gravity in f/r/u frame
float gf = -g * sinf(theta);
float gr =  g * cosf(theta) * sinf(phi);
float gu = -g * cosf(theta) * cosf(phi);

float speed = sqrtf(vf*vf + vr*vr + vu*vu);

// drag
float adf = -K_drag * speed * vf;
float adr = -K_drag * speed * vr;
float adu = -K_drag * speed * vu;

// lift direction from +u, perpendicular to velocity
float vhat_f = vf / speed;
float vhat_r = vr / speed;
float vhat_u = vu / speed;

// u_axis = (0, 0, 1)
float dot_u_v = vhat_u;

float lift_f = 0.0f - dot_u_v * vhat_f;
float lift_r = 0.0f - dot_u_v * vhat_r;
float lift_u = 1.0f - dot_u_v * vhat_u;

float lift_len = sqrtf(lift_f*lift_f + lift_r*lift_r + lift_u*lift_u);

if (lift_len > 1e-6f) {
    lift_f /= lift_len;
    lift_r /= lift_len;
    lift_u /= lift_len;
} else {
    lift_f = 0.0f;
    lift_r = 0.0f;
    lift_u = 1.0f;
}

float lift_accel = K_lift * speed * speed;

float alf = lift_accel * lift_f;
float alr = lift_accel * lift_r;
float alu = lift_accel * lift_u;

// total acceleration
float af = adf + alf + gf;
float ar = adr + alr + gr;
float au = adu + alu + gu;

// integrate
vf += af * dt;
vr += ar * dt;
vu += au * dt;

pf += vf * dt;
pr += vr * dt;
pu += vu * dt;
```

nメートル先を取る場合:

```c
if (pf >= target_distance_m) {
    float alpha = (target_distance_m - pf_prev) / (pf - pf_prev);

    float pr_n = pr_prev + alpha * (pr - pr_prev);
    float pu_n = pu_prev + alpha * (pu - pu_prev);

    screen_x_m = pr_n;
    screen_y_m = pu_n;
}
```

## プロット仕様

初期プロットは次を基本とする。

```text
距離: 0〜40m
間隔: 2m
点数: 21点
```

```text
0, 2, 4, ..., 40
```

表示上は、10mごとに強調してもよい。

```text
2mごと: 小さい点
10mごと: 大きい点または色違い
ゼロイン距離: 強調表示
```

## 将来的な課題

初期モデルでは次を固定または未対応とする。

```text
C_Dの速度/スピン依存
C_Lの速度/スピン依存
BB弾の回転数
回転減衰
遠方で強くホップアップする挙動
弾種切替
実射補正
ゼロイン実測調整
サイト高実測調整
```

遠方でフラットに飛んだ後に強くホップアップするような実弾道を再現するには、少なくとも次が必要になる可能性がある。

```text
S = rBB × omega / speed
C_L = f(S)
omegaの減衰
必要なら C_D = f(S, speed)
```

ただし、これは初期弾道予測モデルの完了条件には含めない。

## 初期モデルの完了条件

```text
- 固定値から0〜40m/2m刻みの弾道点を計算できる。
- LCDへ予測点を描画できる。
- pitchで重力方向のf/u成分が変化する。
- rollで重力方向のr/u成分が変化する。
- 揚力は+u基準で速度に垂直に働く。
- 抗力は速度と逆向きに働く。
- yaw、風、地面、射撃中の姿勢変化は扱わない。
```

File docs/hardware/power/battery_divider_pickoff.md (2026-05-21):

# VIDEO SIGHT バッテリー分圧取り出し位置

対象経路:

```text
18650 -- (A) -- SW -- (B) -- AO3401A -- (C) -- XIAO BAT
```

## 判断

バッテリー分圧は `(C)` から取る。

理由:

- ファームが読みたいのは、実際にXIAOへ届いている電源電圧。
- SW OFF時はXIAOもOFFなので測定不要。Cから取れば分圧抵抗の常時消費も切れる。
- AO3401Aの電圧降下込みで、実際のシステム電圧を監視できる。
- 逆接時にADC/分圧回路もQ1の保護下に入る。

## A/B/C比較

### A: 電池直後

利点:

- 純粋なセル電圧を測れる。

欠点:

- 物理SW OFFでも分圧抵抗が電池に常時接続される。
- 逆接保護の外側になる。
- XIAOがOFFの時に測っても使い道が少ない。

### B: SW後、AO3401A前

利点:

- SW OFF時には分圧消費が切れる。

欠点:

- 逆接保護の前段なので、ADC/分圧が保護外になる。
- AO3401Aの電圧降下を含まない。

### C: AO3401A後、XIAO BAT側

利点:

- SW OFF時に分圧消費が切れる。
- 逆接保護後なので安全。
- XIAOへ実際に入る電圧を測れる。
- ADC入力保護として自然。

欠点:

- AO3401Aの電圧降下後の値になる。ただし通常負荷では数十mV以下で、実用上は問題になりにくい。

## 結論

```text
18650 -- SW -- AO3401A -- (C) -- XIAO BAT
                         └─ 470kΩ/220kΩ分圧 → D3/GPIO4 ADC
```

C点から分圧し、分圧下側はGNDへ接続する。

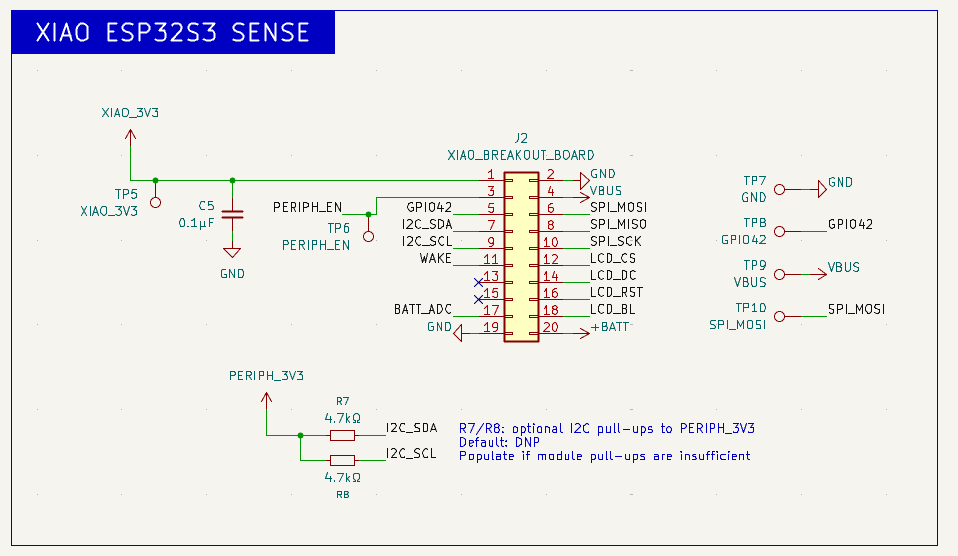
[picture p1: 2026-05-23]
hardware/screenshots/20260523/スクリーンショット 2026-05-23 230700.png

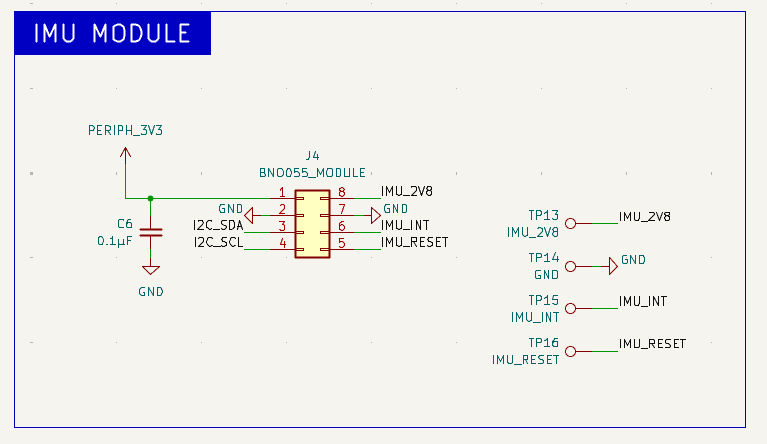
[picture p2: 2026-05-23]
hardware/screenshots/20260523/スクリーンショット 2026-05-23 230725.png

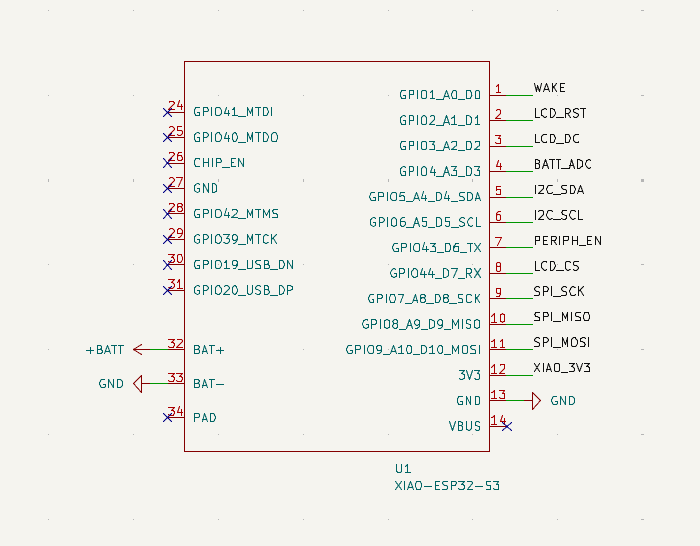
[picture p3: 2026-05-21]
hardware/screenshots/20260521/スクリーンショット 2026-05-21 224933.png

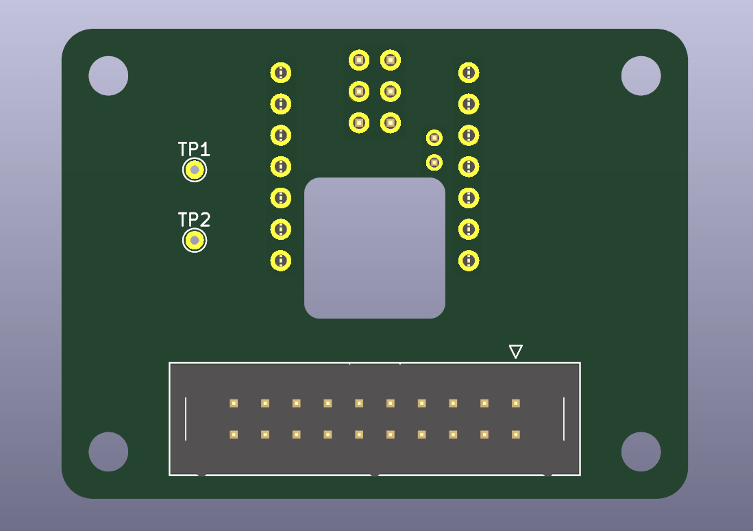
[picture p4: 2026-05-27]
hardware/screenshots/20260527/スクリーンショット 2026-05-27 230657.png

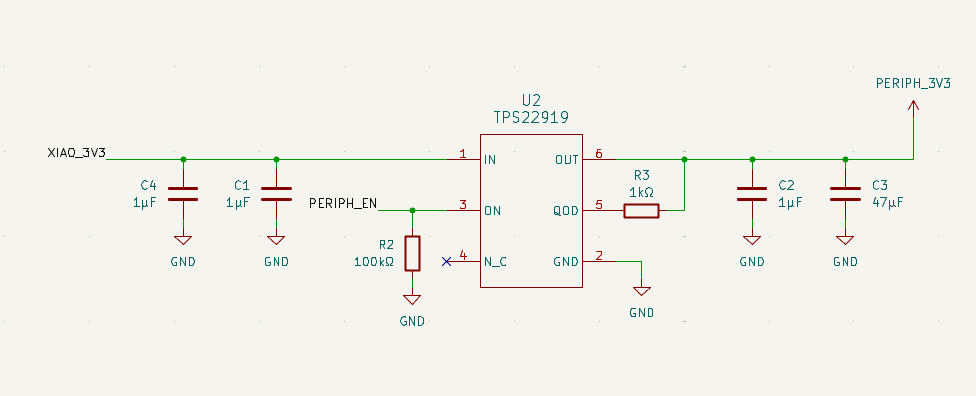
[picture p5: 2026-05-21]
hardware/screenshots/20260521/スクリーンショット 2026-05-21 224951.png

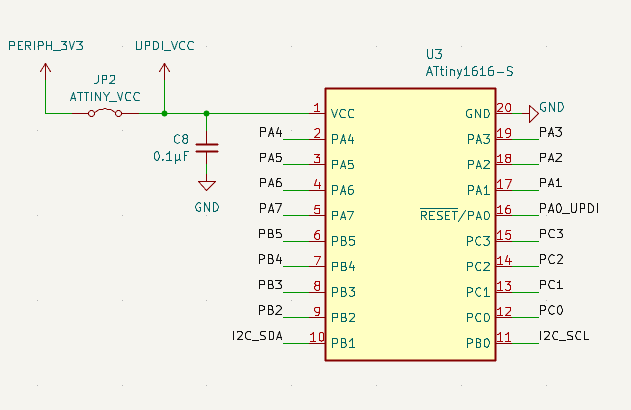
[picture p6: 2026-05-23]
hardware/screenshots/20260523/スクリーンショット 2026-05-23 184052.png

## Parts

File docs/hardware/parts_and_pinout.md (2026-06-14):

# 主要部品
## メインMCU
XIAO ESP32-S3 Sense
[Getting Started with Seeed Studio XIAO ESP32-S3 Series | Seeed Studio Wiki](https://wiki.seeedstudio.com/xiao_esp32s3_getting_started/)

## カメラ
XIAO ESP32-S3 Sense付属カメラ / OV3660
- 最大解像度: 2048x1536
- VGA保存BMPでの実測FOV: 水平 約90.00° / 垂直 約74.32° (1m先の150x300mm差し金が48x95px)
- 1倍ライブビュー初期クロップ: QXGA/UXGA RGB565は`capture failed`となったため、XGAで中央101x118pxを約2.4倍表示。150mm視距離でほぼ1倍。詳細は `docs/hardware/bringup/camera_fov_snapshot.md`。
[Seeed Studio Wiki](https://wiki.seeedstudio.com/xiao_esp32s3_getting_started/#installation-of-expansion-boards-for-sense)

## ディスプレイ
Waveshare 1.83inch LCD Module Rev2 / ST7789P
- 表示領域: 240x284 (実機確認済み)
- 使用向き: rotation 0
- 角丸形状のため四隅は安全領域外として扱う
[1.83inch LCD Module - Waveshare Wiki](https://www.waveshare.com/wiki/1.83inch_LCD_Module)

## IMU
BNO055モジュール
[BNO055使用 9軸センサーフュージョンモジュールキット: 計測器・センサー・ロガー 秋月電子通商-電子部品・ネット通販](https://akizukidenshi.com/catalog/g/g116996/)

## サブMCU
ATtiny1616
[AVRマイコン ATTINY1616-SFR: 半導体 秋月電子通商-電子部品・ネット通販](https://akizukidenshi.com/catalog/g/g130947/)

## 入力装置
- サブMCU配下
	- 4xタクトスイッチ
	- 1xロータリーエンコーダー (ボタンなし)
- メインMCU配下
	- 1xタクトスイッチ

## バッテリー
18650バッテリー
XIAOのバッテリー端子に接続

# ピンアサイン

|XIAO Pin|GPIO|用途|
|---|--:|---|
|D0|GPIO1|Wakeボタン (DeepSleep復帰)|
|D1|GPIO2|LCD_RST|
|D2|GPIO3|LCD_DC|
|D3|GPIO4|バッテリー分圧ADC入力|
|D4|GPIO5|I2C SDA (IMU/サブMCU)|
|D5|GPIO6|I2C SCL (IMU/サブMCU)|
|D6|GPIO43|LCD_BL (PWM調光)|
|D7|GPIO44|SPI CS (LCD)|
|D8|GPIO7|SPI SCK (LCD/SD共有)|
|D9|GPIO8|SPI MISO (SD)|
|D10|GPIO9|SPI MOSI (LCD/SD共有)|
|D11|GPIO42|予備/背面パッド引き出し (マイク用ジャンパー注意)|
|D12|GPIO41|PERIPH_EN (TPS22919周辺電源制御、背面パッド引き出し)|
|(基板内蔵配線)|GPIO21|SPI CS (SD、実機確認済み)|

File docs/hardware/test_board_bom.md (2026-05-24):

# VIDEO SIGHT test board BOM

Source schematic: `hardware/kicad/video_sight_test_board/video_sight_test_board.kicad_sch`

Updated after ERC fixes:

- `SW2` WAKE switch added.
- `TP10` corrected to `SPI_MISO`.
- R7/R8 optional I2C pull-ups are marked DNP in KiCad.

## Board-mounted parts

| Ref | Qty | Part / value | Footprint | Populate | Notes |
|---|---:|---|---|---|---|
| C1, C2 | 2 | 1µF | `Capacitor_SMD:C_0805_2012Metric_Pad1.18x1.45mm_HandSolder` | Yes | TPS22919 input/output local capacitors. X7R recommended. |
| C3, C4 | 2 | 47µF | `@自分用:CAP_FN_B_PAN` | Yes | Bulk capacitors. Custom/local footprint; verify polarity and physical size before order. |
| C5, C6, C7, C8 | 4 | 0.1µF | `Capacitor_SMD:C_0805_2012Metric_Pad1.18x1.45mm_HandSolder` | Yes | Local decoupling. C8 is on the `UPDI_VCC` / ATtiny VCC side of JP2. |
| C9 | 1 | 0.047µF | `Capacitor_SMD:C_0805_2012Metric_Pad1.18x1.45mm_HandSolder` | Yes | Battery ADC smoothing capacitor. |
| J1 | 1 | BATTERY connector | `Connector_JST:JST_XH_B2B-XH-A_1x02_P2.50mm_Vertical` | Yes | Battery input connector. Confirm mating cable/housing and current rating. |
| J2 | 1 | XIAO breakout board connector | `Connector_IDC:IDC-Header_2x10_P2.54mm_Vertical` | Yes | Keyed IDC cable connection. Confirm key direction and pin 1 before PCB order. |
| J3 | 1 | LCD connector | `Connector_PinHeader_2.54mm:PinHeader_1x08_P2.54mm_Vertical` | Yes | For Waveshare LCD cable/header. Bundled cable can be reversed; final build may need keyed/custom cable. |
| J4 | 1 | BNO055 module socket/header | `Package_DIP:DIP-8_W7.62mm_Socket` | Yes | Fits 2x4 / 2.54mm / 7.62mm row spacing module if measured module matches. |
| J5 | 1 | UPDI header | `Connector_PinHeader_2.54mm:PinHeader_1x03_P2.54mm_Vertical` | Yes | `UPDI_VCC`, GND, PA0/UPDI programming header. |
| J6, J7 | 2 | ATtiny1616 breakout headers | `Connector_PinHeader_2.54mm:PinHeader_1x08_P2.54mm_Vertical` | Yes | Expose ATtiny pins for jumper experiments. |
| J8 | 1 | INPUT_DEVICE header | `Connector_PinHeader_2.54mm:PinHeader_1x06_P2.54mm_Vertical` | Yes | Buttons/encoder external wiring point. |
| JP1 | 1 | BATT_CURRENT jumper | `Connector_PinHeader_2.54mm:PinHeader_1x02_P2.54mm_Vertical` | Yes | Remove jumper to insert ammeter for battery current measurement. |
| JP2 | 1 | ATTINY_VCC jumper | `Connector_PinHeader_2.54mm:PinHeader_1x02_P2.54mm_Vertical` | Yes | Closed for normal operation; open for programmer-powered ATtiny-only mode. |
| Q1 | 1 | AO3401A P-MOSFET | `Package_TO_SOT_SMD:SOT-23` | Yes | Reverse-polarity protection. Pin map checked: `1=G`, `2=S`, `3=D`. |
| R1 | 1 | 1MΩ | `Resistor_SMD:R_0805_2012Metric_Pad1.20x1.40mm_HandSolder` | Yes | AO3401A gate pulldown. |
| R2 | 1 | 100kΩ | `Resistor_SMD:R_0805_2012Metric_Pad1.20x1.40mm_HandSolder` | Yes | TPS22919 `PERIPH_EN` pulldown. |
| R3 | 1 | 1kΩ | `Resistor_SMD:R_0805_2012Metric_Pad1.20x1.40mm_HandSolder` | Yes | TPS22919 QOD resistor. |
| R4 | 1 | 470kΩ | `Resistor_SMD:R_0805_2012Metric_Pad1.20x1.40mm_HandSolder` | Yes | Battery ADC divider upper resistor. 1% recommended. |
| R5 | 1 | 220kΩ | `Resistor_SMD:R_0805_2012Metric_Pad1.20x1.40mm_HandSolder` | Yes | Battery ADC divider lower resistor. 1% recommended. |
| R6 | 1 | 470Ω | `Resistor_SMD:R_0805_2012Metric_Pad1.20x1.40mm_HandSolder` | Yes | PA0/UPDI series resistor. |
| R7, R8 | 2 | 4.7kΩ | `Resistor_SMD:R_0805_2012Metric_Pad1.20x1.40mm_HandSolder` | DNP by default | Optional I2C pull-ups to `PERIPH_3V3`. Populate only if BNO055/module pull-ups are insufficient. |
| SW1 | 1 | SW_BATT power switch | `Button_Switch_THT:SW_DIP_SPSTx01_Slide_9.78x4.72mm_W7.62mm_P2.54mm` | Yes | Physical battery power switch. Confirm exact part. |
| SW2 | 1 | WAKE push button | `Button_Switch_THT:SW_PUSH_6mm` | Yes | Added after ERC review. Pulls `WAKE` to GND. |
| SW3, SW4, SW5, SW6 | 4 | UP / DOWN / FRONT / BACK push buttons | `Button_Switch_THT:SW_PUSH_6mm` | Yes | ATtiny input buttons; firmware enables internal pull-ups. |
| SW7 | 1 | Rotary encoder | `Rotary_Encoder:RotaryEncoder_Alps_EC12E_Vertical_H20mm` | Yes | Confirm exact encoder mechanical dimensions and shaft style. |
| TP1 | 1 | BAT+ test point | `TestPoint:TestPoint_THTPad_D1.5mm_Drill0.7mm` | Yes | Battery positive before switch. |
| TP2, TP7, TP12, TP14 | 4 | GND test points | `TestPoint:TestPoint_THTPad_D1.5mm_Drill0.7mm` | Yes | Probe/logic analyzer ground points. |
| TP3 | 1 | BAT_SW test point | `TestPoint:TestPoint_THTPad_D1.5mm_Drill0.7mm` | Yes | Battery after physical switch, before protection MOSFET. |
| TP4 | 1 | XIAO_BAT test point | `TestPoint:TestPoint_THTPad_D1.5mm_Drill0.7mm` | Yes | Protected battery input to XIAO BAT. |
| TP5 | 1 | XIAO_3V3 test point | `TestPoint:TestPoint_THTPad_D1.5mm_Drill0.7mm` | Yes | Unswitched XIAO 3.3V rail. |
| TP6 | 1 | PERIPH_EN test point | `TestPoint:TestPoint_THTPad_D1.5mm_Drill0.7mm` | Yes | Load switch enable from GPIO41/D12 pad. |
| TP8 | 1 | GPIO42 test point | `TestPoint:TestPoint_THTPad_D1.5mm_Drill0.7mm` | Yes | Spare XIAO backside pad / D11. |
| TP9 | 1 | VBUS test point | `TestPoint:TestPoint_THTPad_D1.5mm_Drill0.7mm` | Yes | XIAO USB/VBUS observation. |
| TP10 | 1 | SPI_MISO test point | `TestPoint:TestPoint_THTPad_D1.5mm_Drill0.7mm` | Yes | Corrected from MOSI to MISO after ERC review. |
| TP11 | 1 | PERIPH_3V3 test point | `TestPoint:TestPoint_THTPad_D1.5mm_Drill0.7mm` | Yes | Switched peripheral 3.3V rail. |
| TP13 | 1 | IMU_2V8_OUT test point | `TestPoint:TestPoint_THTPad_D1.5mm_Drill0.7mm` | Yes | Observe-only module rail/test point. Do not drive. |
| TP15 | 1 | IMU_INT test point | `TestPoint:TestPoint_THTPad_D1.5mm_Drill0.7mm` | Yes | BNO055 interrupt observation. |
| TP16 | 1 | IMU_RESET test point | `TestPoint:TestPoint_THTPad_D1.5mm_Drill0.7mm` | Yes | BNO055 reset observation/control. |
| U1 | 1 | TPS22919 load switch | `@自分用:DCK0006A_L` | Yes | Custom/local footprint. Verify pin map and package before order. |
| U2 | 1 | ATTINY1616-SN | `Package_SO:SOIC-20W_7.5x12.8mm_P1.27mm` | Yes | ATtiny1616 sub-MCU in SOIC-20W. |

## DNP / optional parts

| Ref | Qty | Part | Reason |
|---|---:|---|---|
| R7, R8 | 2 | 4.7kΩ I2C pull-ups | BNO055 module likely has pull-ups. Leave open first; populate only if bus idle/rise time needs it. |

## Off-board / module parts to prepare

These are needed for the prototype but are not all represented as board-mounted KiCad parts.

| Item | Qty | Notes |
|---|---:|---|
| Protected 18650 cell | 1 | Use protected cell as project policy. |
| 18650 holder / battery lead with JST-XH mate | 1 | Must match J1 polarity and protected-cell length. |
| XIAO ESP32-S3 Sense | 1 | Main MCU/camera module side. |
| XIAO breakout board | 1 | Separate breakout/interposer board for camera positioning. |
| Keyed 2x10 IDC cable | 1 | Obtain before PCB order to verify key direction and pin mapping. |
| Waveshare 1.83 inch LCD Rev2 | 1 | ST7789P 240x284 module. Confirm `LCD_BL` behavior. |
| LCD cable / custom keyed cable | 1 | Bundled 2.54mm socket cable is reversible; final build may need keyed/custom cable. |
| AE-BNO055-BO / BNO055 module | 1 | Mounts to J4 if row spacing matches. |
| Jumper shunts | 2+ | For JP1 BATT_CURRENT and JP2 ATTINY_VCC. |
| UPDI programmer | 1 | For ATtiny1616 programming. Use JP2 correctly when programmer supplies VCC. |

## Pre-order checks

- Run ERC again after the BOM update and footprint changes.
- Confirm all DNP parts are exported correctly by KiCad BOM settings.
- Verify custom/local footprints `@自分用:CAP_FN_B_PAN` and `@自分用:DCK0006A_L` in generated Gerbers.
- Confirm IDC cable key orientation and pin 1 before PCB order.
- Confirm LCD cable orientation and whether final hardware needs a keyed/custom cable.
- Confirm `LCD_BL` is safe to drive from GPIO or add a driver if the module exposes raw LED current path.

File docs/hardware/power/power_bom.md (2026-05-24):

# VIDEO SIGHT 電源周り 部品表ドラフト

このファイルは電源周りだけの抜粋です。最新の全体BOMは次を参照してください。

```text
docs/hardware/test_board_bom.md
```

Source schematic: `hardware/kicad/video_sight_test_board/video_sight_test_board.kicad_sch`

## 前提構成

```text
Protected 18650
  → J1 BATTERY
  → SW1 physical power switch
  → Q1 AO3401A P-MOSFET reverse-polarity protection
  → JP1 BATT_CURRENT
  → XIAO_BAT / XIAO BAT+

XIAO_3V3
  → U1 TPS22919 load switch
  → PERIPH_3V3
      - LCD VCC
      - BNO055 VCC
      - ATtiny1616 VCC through JP2

GPIO41/D12 pad
  → PERIPH_EN
  → U1 TPS22919 ON

D6/GPIO43
  → LCD_BL

XIAO_BAT / +BATT sense
  → R4/R5 divider
  → BATT_ADC
```

## Power-related BOM

| Ref | Qty | 部品 | 値 / 型番 | Footprint | Populate | 用途 | 備考 |
|---|---:|---|---|---|---|---|---|
| J1 | 1 | Battery connector | JST-XH 2pin | `Connector_JST:JST_XH_B2B-XH-A_1x02_P2.50mm_Vertical` | Yes | Battery input | Polarity確認。 |
| SW1 | 1 | Physical power switch | SPST slide switch | `Button_Switch_THT:SW_DIP_SPSTx01_Slide_9.78x4.72mm_W7.62mm_P2.54mm` | Yes | 完全OFF | 実部品寸法/電流定格確認。 |
| Q1 | 1 | P-MOSFET | AO3401A | `Package_TO_SOT_SMD:SOT-23` | Yes | 逆接保護 | Pin map checked: `1=G`, `2=S`, `3=D`。 |
| R1 | 1 | Gate pulldown | 1MΩ | 0805 hand-solder | Yes | Q1 gate-GND | 物理ON時の消費を小さくする。 |
| JP1 | 1 | Current-measure jumper | 2pin header | `PinHeader_1x02_P2.54mm_Vertical` | Yes | Battery current measurement | 通常時はジャンパ短絡。測定時は外して電流計を直列。 |
| U1 | 1 | Load switch | TPS22919 | `@自分用:DCK0006A_L` | Yes | `PERIPH_3V3` control | Custom/local footprint。Gerberで必ず確認。 |
| R2 | 1 | EN pulldown | 100kΩ | 0805 hand-solder | Yes | `PERIPH_EN` default off | Reset/DeepSleep時に周辺電源OFFへ倒す。 |
| R3 | 1 | QOD resistor | 1kΩ | 0805 hand-solder | Yes | TPS22919 QOD tuning | OUT放電用。 |
| C1 | 1 | Input bypass | 1µF | 0805 hand-solder | Yes | TPS22919 IN-GND | U1近傍。 |
| C2 | 1 | Output bypass | 1µF | 0805 hand-solder | Yes | TPS22919 OUT-GND | U1近傍。 |
| C3 | 1 | Peripheral bulk capacitor | 47µF | `@自分用:CAP_FN_B_PAN` | Yes | `PERIPH_3V3` bulk | 極性/サイズ/耐圧確認。 |
| C4 | 1 | XIAO_3V3 bulk capacitor | 47µF | `@自分用:CAP_FN_B_PAN` | Yes | `XIAO_3V3` bulk | 極性/サイズ/耐圧確認。 |
| R4 | 1 | Battery divider upper | 470kΩ | 0805 hand-solder | Yes | Battery ADC | 1%推奨。 |
| R5 | 1 | Battery divider lower | 220kΩ | 0805 hand-solder | Yes | Battery ADC | 1%推奨。 |
| C9 | 1 | ADC smoothing capacitor | 0.047µF | 0805 hand-solder | Yes | `BATT_ADC` smoothing | 高抵抗分圧の読み取り安定化。 |
| TP1 | 1 | Test point | BAT+ | THT pad D1.5/D0.7 | Yes | 電池正極測定 |  |
| TP2, TP7, TP12, TP14 | 4 | Test point | GND | THT pad D1.5/D0.7 | Yes | 測定GND | 複数配置。 |
| TP3 | 1 | Test point | BAT_SW | THT pad D1.5/D0.7 | Yes | スイッチ後測定 |  |
| TP4 | 1 | Test point | XIAO_BAT | THT pad D1.5/D0.7 | Yes | XIAO BAT入力測定 |  |
| TP5 | 1 | Test point | XIAO_3V3 | THT pad D1.5/D0.7 | Yes | XIAO 3.3V測定 |  |
| TP6 | 1 | Test point | PERIPH_EN | THT pad D1.5/D0.7 | Yes | Load-switch EN測定 |  |
| TP9 | 1 | Test point | VBUS | THT pad D1.5/D0.7 | Yes | USB/VBUS観測 |  |
| TP11 | 1 | Test point | PERIPH_3V3 | THT pad D1.5/D0.7 | Yes | 周辺3.3V測定 |  |

## Battery divider

```text
R4 = 470kΩ
R5 = 220kΩ
C9 = 0.047µF
```

Approximate ADC node voltage:

```text
4.2V -> 1.34V
3.7V -> 1.18V
3.0V -> 0.96V
```

Divider current:

```text
4.2V / (470kΩ + 220kΩ) ≈ 6.1µA
```

## Notes

- `R7/R8` optional I2C pull-ups are not included here because they are not power-path parts; see the full BOM.
- `SW2` WAKE was added after ERC review; it is listed in the full BOM.
- `TP10` is now `SPI_MISO`; it is listed in the full BOM.
- Custom/local footprints should be checked in Gerber output before ordering.

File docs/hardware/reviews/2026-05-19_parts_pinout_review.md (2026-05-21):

# VIDEO SIGHT 部品構成・ピンアサインレビュー

## 確認した外部仕様

- Seeed XIAO ESP32-S3 Sense wiki上のピン表では、D4=GPIO5/SDA、D5=GPIO6/SCL、D8=GPIO7/SCK、D9=GPIO8/MISO、D10=GPIO9/MOSI。
- Seeed の pin multiplexing ページでは Sense 側の microSD は CS=GPIO21、SCK=D8/GPIO7、MISO=D9/GPIO8、MOSI=D10/GPIO9 と記載されている。Getting Startedページ側のGPIO3記載よりこちらを正とする。
- Waveshare 1.83inch LCD Module は SPI。使用品は Rev2 / ST7789P / 240x284 とする。基板プリントが240x280でも、Rev1からの表示残りとして扱い、まず仕様値240x284で実装する。表示領域は約30.197 x 35.230 mm。

## 主要レビュー

### 良い点

- XIAO ESP32-S3 Sense + 付属DVPカメラ + SPI LCD の構成は、CVBS変換が不要で試作性が高い。
- BNO055をI2C、ATtiny1616 UIサブMCUもI2C候補にする構成はGPIO節約に向く。
- ATtiny1616に4ボタン+ロータリーエンコーダを集約する方針は、メイン側の映像/LCD/IMU処理遅延を抑えやすい。
- D0/GPIO1をWakeボタン専用にするのは役割が明確。
- LCD_BLをPWM可能なGPIO43へ置く案は自然。

### 要確認・修正候補

1. SD CSの割り当て

訂正: Sense拡張ボードのmicroSD CSは GPIO21 とする。Getting Startedページ側にはGPIO3と読める記載があるが、pin multiplexingページではGPIO21で、実機情報とも合う。したがって現在案の「基板内蔵配線 GPIO21 = SPI CS(SD)」は妥当。

影響:

- D2/GPIO3 を LCD_DC として使う案は、SD CSとは衝突しない。
- SDとLCDは SCK/MISO/MOSI を共有し、CSを分ける構成でよい。
- ただしSD使用時はSPIバス帯域をLCD更新と共有するため、同時アクセス時の表示遅延に注意する。

2. D11/D12の扱い

Seeed wikiでは GPIO42/41 はデジタルマイクのCLK/DATAにも使われる。案の通りJPカットで外部使用可能にするならよいが、マイクは使えなくなる前提を明記する。

3. Waveshare LCD revision差

使用するLCDは Rev2 とし、コントローラは ST7789P、解像度は 240x284 として実装する。モジュール上の印字が240x280でも、Rev1由来の印字残りと見なし、まず仕様値を優先する。

実装時の確認:

- ST7789系初期化で動かす
- 論理高さを284にする
- 画面端4pxの扱いを実機で確認する
- もし下端/上端に乱れや非表示が出る場合だけ、実効表示領域を240x280へ落とす

4. I2Cバス

BNO055とATtiny1616を共有するなら、以下を設計メモに入れる。

- BNO055アドレス: 通常0x28または0x29
- ATtiny1616 UIサブMCU: 0x30など、衝突しにくい固定アドレス候補
- プルアップ抵抗はモジュール側搭載分を確認し、合成抵抗が強すぎないようにする
- すべて3.3V駆動に統一

5. BNO055の使い方

BNO055は姿勢推定が楽だが、エアガン周辺では磁気センサが乱れる可能性がある。弾道補正に使う主軸はロール/ピッチとし、ヨーや絶対方位は信用しすぎない。

6. バッテリーADC

D3/GPIO4で分圧測定するなら、ディープスリープ時の常時消費を避けるため、分圧抵抗を高めにするか、P-MOS/N-MOS等で測定時だけ分圧を有効にする設計が望ましい。

## 暫定結論

全体構成は現実的。SD CSは GPIO21 として扱うため、現在の D2/GPIO3=LCD_DC はSDとは衝突しない。LCDは Rev2 / ST7789P / 240x284 として実装し、実機で端4pxの表示を確認する。

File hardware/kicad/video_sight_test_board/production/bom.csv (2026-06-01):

Designator | Footprint | Quantity | Value | LCSC Part #
_193, _192, _191, _190, _189, _188, _187, _186, _185, _184, _183, _182, _181, _180, _179, _178, _177, _176, _175, _174, _173, _172, _171, _170, _169, _168, _167, _166, _165, _164, _163, _162, _161, _160, _159, _158, _157, _156, _155, _154, _153, _152, _151, _150, _149, _148, _147, _146, _145, _144, _143, _142, _141, _140, _139, _138, _137, _136, _135, _134, _133, _132, _131, _130, _129, _128, _127, _126, _125, _124, _123, _122, _121, _120, _119, _118, _117, _116, _115, _114, _113, _112, _111, _110, _109, _108, _107, _106, _105, _104, _103, _102, _101, _100, _99, _98, _97, _96, _95, _94, _93, _92, _91, _90, _89, _88, _87, _86, _85, _84, _83, _82, _81, _80, _79, _78, _77, _76, _75, _74, _73, _72, _71, _70, _69, _68, _67, _66, _65, _64, _63, _62, _61, _60, _59, _58, _57, _56, _55, _54, _53, _52, _51, _50, _49, _48, _47, _46, _45, _44, _43, _42, _41, _40, _39, _38, _37, _36, _35, _34, _33, _32, _31, _30, _29, _28, _27, _26, _25, _24, _23, _22, _21, _20, _19, _18, _17, _16, _15, _14, _13, _12, _11, _10, _9, _8, _7, _6, _5, _4, _3, _2, |  | 193
C1, C2 | 0805 | 2 | 1μF
C3, C4 | CAP_FN_B_PAN | 2 | 47μF
C5, C6, C7, C8 | 0805 | 4 | 0.1μF
C9 | 0805 | 1 | 0.047μF
J1 | JST_XH_B2B-XH-A_1x02_P2.50mm_Vertical | 1 | BATTERY
J2 | IDC-Header_2x10_P2.54mm_Vertical | 1 | XIAO
J3 | PinHeader_1x08_P2.54mm_Vertical | 1 | LCD
J4 | DIP-8_W7.62mm_Socket | 1 | BNO055
J5 | PinHeader_1x03_P2.54mm_Vertical | 1 | UPDI
J6 | PinHeader_1x08_P2.54mm_Vertical | 1 | ATtiny1616_LEFT
J7 | PinHeader_1x08_P2.54mm_Vertical | 1 | ATtiny1616_RIGHT
J8 | PinHeader_1x06_P2.54mm_Vertical | 1 | INPUT_DEVICE
JP1 | PinHeader_1x02_P2.54mm_Vertical | 1 | BATT_CURRENT
JP2 | PinHeader_1x02_P2.54mm_Vertical | 1 | ATTINY_VCC
Q1 | SOT-23 | 1 | AO3401A
R1 | 0805 | 1 | 1MΩ
R2 | 0805 | 1 | 100kΩ
R3 | 0805 | 1 | 1kΩ
R4 | 0805 | 1 | 470kΩ
R5 | 0805 | 1 | 220kΩ
R6 | 0805 | 1 | 470Ω
R7, R8 | 0805 | 2 | 4.7kΩ
SW1 | SW_DIP_SPSTx01_Slide_9.78x4.72mm_W7.62mm_P2.54mm | 1 | SW_BATT
SW2 | SW_PUSH_6mm | 1 | WAKE
SW3 | SW_PUSH_6mm | 1 | UP
SW4 | SW_PUSH_6mm | 1 | DOWN
SW5 | SW_PUSH_6mm | 1 | FRONT
SW6 | SW_PUSH_6mm | 1 | BACK
SW7 | RotaryEncoder_Alps_EC12E_Vertical_H20mm | 1 | RotaryEncoder
TP1, TP12, TP14, TP7 | TestPoint_THTPad_D1.5mm_Drill0.7mm | 4 | GND
TP10 | TestPoint_THTPad_D1.5mm_Drill0.7mm | 1 | MISO
TP11 | TestPoint_THTPad_D1.5mm_Drill0.7mm | 1 | PERIPH_3V3
TP13 | TestPoint_THTPad_D1.5mm_Drill0.7mm | 1 | 2V8_OUT
TP15 | TestPoint_THTPad_D1.5mm_Drill0.7mm | 1 | INT
TP16 | TestPoint_THTPad_D1.5mm_Drill0.7mm | 1 | RESET
TP2 | TestPoint_THTPad_D1.5mm_Drill0.7mm | 1 | BAT+
TP3 | TestPoint_THTPad_D1.5mm_Drill0.7mm | 1 | BAT_SW
TP4 | TestPoint_THTPad_D1.5mm_Drill0.7mm | 1 | XIAO_BAT
TP5 | TestPoint_THTPad_D1.5mm_Drill0.7mm | 1 | 3V3
TP6 | TestPoint_THTPad_D1.5mm_Drill0.7mm | 1 | EN
TP8 | TestPoint_THTPad_D1.5mm_Drill0.7mm | 1 | GPIO42
TP9 | TestPoint_THTPad_D1.5mm_Drill0.7mm | 1 | VBUS
U1 | DCK0006A_L | 1 | TPS22919
U2 | SOIC-20W_7.5x12.8mm_P1.27mm | 1 | ATTINY1616-SN

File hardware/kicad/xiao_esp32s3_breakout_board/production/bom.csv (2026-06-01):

Designator | Footprint | Quantity | Value | LCSC Part #
J1 | IDC-Header_2x10_P2.54mm_Vertical | 1 | XIAO_BREAKOUT_BOARD
J2 | PinHeader_2x03_P2.54mm_Vertical | 1 | Conn_02x03_Odd_Even
J3 | PinHeader_1x02_P2.00mm_Vertical | 1 | Conn_01x02_Pin
J4, J5 | PinSocket_1x07_P2.54mm_Vertical | 2 | Conn_01x07_Socket
TP1 | TestPoint_THTPad_D1.5mm_Drill0.7mm | 1 | CHIP_EN
TP2 | TestPoint_THTPad_D1.5mm_Drill0.7mm | 1 | GND

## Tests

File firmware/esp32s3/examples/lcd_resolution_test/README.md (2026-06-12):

# LCD解像度確認テスト

Waveshare 1.83inch LCD Module Rev2 / ST7789P の動作確認と、表示可能領域の解像度確認用PlatformIO example。

## 対象

- MCU: Seeed Studio XIAO ESP32S3 Sense
- LCD: Waveshare 1.83inch LCD Module Rev2
- Controller: ST7789P
- 確定表示領域: 240 x 284
- 確定使用向き: rotation 0
- 確定オフセット: 0,0

## 実行

```bash
cd firmware/esp32s3/examples/lcd_resolution_test
pio run
pio run -t upload
pio device monitor
```

## 確認ポイント

起動後、次の表示を約3.5秒ごとに切り替える。

- rotation 0/1/2/3 の解像度確認パターン
- 赤、緑、青、白の全画面塗りつぶし

確認すること:

- 白い外枠が4辺すべて見える
- 4隅の `TL` / `TR` / `BL` / `BR` ブロックは、LCDの角丸形状によって角だけ欠ける
- rotation 0/2 で `visible=240x284` と表示される
- rotation 1/3 で `visible=284x240` と表示される
- 色順が自然で、赤・緑・青が入れ替わっていない

## 実機確認結果

Issue #6 の写真で確認済み。

- 白い枠線は4辺とも見えている
- 解像度は `240 x 284` で確定
- VIDEO SIGHTでは `rotation 0` を使用する
- `offset=0,0` でよい
- 角丸ディスプレイのため四隅は物理的に欠ける
- 黄色い20px目盛りの2本目付近からカーブが始まるように見える
- 色表示に違和感はない

## オフセット調整

表示が上下にずれる、外枠が欠ける、余白が片側に寄る場合は、`src/main.cpp` 冒頭付近の値を変更して再ビルドする。

```cpp
constexpr int LCD_OFFSET_X = 0;
constexpr int LCD_OFFSET_Y = 0;
```

ST7789系では縦方向オフセットとして `0`, `20`, `36`, `40` 付近が候補になる。VIDEO SIGHTで実機確認後、確定値を本体ファーム側へ反映する。

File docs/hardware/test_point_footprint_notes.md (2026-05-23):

# Test point footprint notes

## Goal

Choose practical test-point footprints for the first VIDEO SIGHT test board.

The board has enough space, so prioritize ease of hand probing, bring-up, and rework over density.

## Recommended default

Use through-hole loop / turret-style or large plated test pads for most important test points.

Recommended KiCad-style choices:

```text
Important power/debug rails:
  TestPoint:TestPoint_THTPad_D1.5mm_Drill0.7mm
  or similar 1.5mm+ plated pad

Dense or low-priority signal-only points:
  TestPoint:TestPoint_Pad_D1.0mm
  or similar 1.0mm SMD pad
```

If a wire may be soldered during bring-up, prefer THT pads over tiny SMD pads.

## By signal class

### Power rails and grounds

Use larger THT pads or loop test points.

Signals:

```text
BAT+
BAT_SW
XIAO_BAT
XIAO_3V3
PERIPH_3V3
VBUS
GND
```

Recommendation:

```text
1.5mm to 2.0mm plated pad, 0.7mm to 1.0mm drill
```

Rationale:

- easy multimeter probing,
- can clip or solder temporary wires,
- useful for current/voltage bring-up,
- mechanically stronger.

Place at least two or three GND test points around the board if space allows.

### Control and reset lines

Use medium pads; THT is still preferred on a test board.

Signals:

```text
PERIPH_EN
LCD_BL
LCD_RST
IMU_RESET
WAKE
PA0_UPDI
```

Recommendation:

```text
1.0mm to 1.5mm pad
THT if likely to be jumpered; SMD pad if only oscilloscope probing
```

### Digital buses

Use small-to-medium SMD pads or compact THT pads.

Signals:

```text
SPI_MOSI
SPI_MISO
SPI_SCK
LCD_CS
LCD_DC
I2C_SDA
I2C_SCL
IMU_INT
```

Recommendation:

```text
1.0mm SMD pad, or 1.0mm/0.5mm THT pad if temporary wires may be soldered
```

For oscilloscope/logic analyzer probing, place a nearby GND point.

### Observe-only module rails

Signals:

```text
IMU_2V8
```

Recommendation:

```text
small or medium pad, clearly labeled observe-only
```

Do not make it look like a normal power input/output rail.

## Preferred scheme for this board

Because this is a spacious first test board, use two sizes:

```text
TP_BIG:
  THT pad, D1.5mm to D2.0mm, drill 0.7mm to 1.0mm
  For power rails, GND, current/bring-up points, UPDI/power-control lines.

TP_SMALL:
  SMD pad D1.0mm or compact THT pad
  For SPI/I2C/control observations.
```

If keeping things simpler, use the larger THT pad for almost all test points. The board is for bring-up, not production density.

## Layout notes

- Put GND test points near SPI/I2C groups for oscilloscope ground reference.
- Put one GND near battery/power input and one near peripheral rail.
- Label each TP with both reference and net name if space allows.
- Keep high-current paths short and wide; test pads should not accidentally become narrow series bottlenecks.
- For power rails, avoid tiny SMD-only points unless the signal is only for voltage measurement.
- For optional jumper-like debugging, use 2-pin headers or solder jumpers, not ordinary one-pad test points.

## VIDEO SIGHT recommendation

For the first test board:

```text
Power/GND/UPDI/PERIPH_EN:
  large THT test pads, about 1.5mm pad / 0.7mm drill or larger

SPI/I2C/LCD/IMU_INT:
  1.0mm SMD pads are acceptable, but THT pads are more convenient if space allows

GND:
  use several large THT pads across the board
```

This makes the board easier to debug with a multimeter, scope probe, logic analyzer, or temporary jumper wires.

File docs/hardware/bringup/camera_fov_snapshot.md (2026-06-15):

# カメラライブ表示・FOV測定スナップショット

## 目的

XIAO ESP32S3 Sense付属カメラのライブ画像をLCDへ表示し、FOV測定用の静止画をmicroSDへ保存する。

## 対象

- MCU: Seeed Studio XIAO ESP32S3 Sense
- Camera: 付属OV3660カメラ
- Camera sensor max: 2048x1536
- LCD: Waveshare 1.83inch LCD Module Rev2 / ST7789P
- LCD表示領域: 240x284, rotation 0
- SD CS: GPIO21
- 撮影ボタン: Wakeボタン D0 / GPIO1, active LOW
- SD初期化: LCDと共有するSPIを `SCK=GPIO7, MISO=GPIO8, MOSI=GPIO9, CS=GPIO21` として明示し、4MHzで初期化する。LovyanGFX側も同じSPI2/FSPIホストで、LCDは4線SPI・MISO有効として設定する。

## 現在の実装

保存する画像は、LCD表示後の画像ではなく、カメラから取得したRGB565フレームをBMPへ変換したもの。

```text
camera frame: XGA 1024x768 / RGB565
SD保存: /fov/fov_0000_1024x768.bmp など
LCD表示: 1024x768中央から150mm視距離の1倍相当101x118をクロップし、240x284へ拡大表示
```

LCD表示用クロップは、実測FOVから1倍表示に近い中央領域を使う。

```text
source: 1024x768
crop:  center 101 x 118 相当
crop origin: x=(1024-101)/2, y=(768-118)/2
result: 240 x 284へ約2.4倍表示
```

実装上は整数演算で、各LCDピクセルに対応する元画像ピクセルをnearest-neighborでサンプリングしている。

## 操作

FOV確認用の実機確認済みスケッチは、通常ファームから切り離して次のPlatformIO例へ退避している。

```text
firmware/esp32s3/examples/camera_fov_snapshot/
```

1. microSDカードを挿入する。
2. FOV確認例を書き込む。
3. LCDにライブ画像が表示されることを確認する。
4. FOV測定対象をカメラ正面に置く。
5. Wakeボタンを押す。
6. `/fov/` 配下にBMPが保存される。

```bash
cd firmware/esp32s3/examples/camera_fov_snapshot
pio run
pio run -t upload
pio device monitor
```

## FOV測定方法

既知サイズの物体を既知距離に置き、保存BMP上のピクセル幅を数える。

水平FOV:

```text
fraction = object_px / image_width_px
full_width_at_distance = object_width_mm / fraction
horizontal_fov = 2 * atan(full_width_at_distance / (2 * distance_mm))
```

垂直FOVも同様に、物体高さと画像高さピクセルで計算する。

## 実測結果

2026-06-14時点のOV3660付属レンズ・VGA保存BMPでの実測値。

```text
測定対象: 150 x 300mmの差し金
距離: カメラから約1000mm
保存画像: 640 x 480px
測定対象の画像上サイズ: 48 x 95px

水平スケール: 150mm / 48px = 3.125mm/px
垂直スケール: 300mm / 95px = 3.158mm/px

1m地点でのカメラ生フレーム全体の見え幅:
  横: 約2000mm
  縦: 約1516mm

カメラ生FOV:
  水平: 約90.00°
  垂直: 約74.32°
```

QXGAおよびUXGA RGB565は `capture failed` となり映像が出なかったため、まずはXGAへ下げる。XGAでは150mm視距離の1倍に近い中央 `101 x 118px` をクロップする。VGA時の約3.8倍拡大より小さい、約2.4倍拡大で表示する初期値である。これにより、1m地点での見え幅はおおよそ次の値になる。

```text
クロップ: 101 x 118px
1m地点での見え幅: 約197 x 233mm
表示FOV: 水平 約11.24° / 垂直 約13.28°
LCDへの拡大率: 横 約2.38倍 / 縦 約2.41倍
```

## 1倍表示の目標

LCDサイズ `29.52 x 34.93mm`、目の距離 `150mm` の場合、1倍相当のLCD見かけ画角は次の値。

```text
水平: 約11.24°
垂直: 約13.28°
対角: 約17.34°
```

1m先では、1倍時の見え幅は次の程度。

```text
横: 約197mm
縦: 約233mm
```

保存BMPからカメラ生FOVを測定し、その後に1倍相当になる中央クロップ量を決める。2026-06-14時点ではXGA `101 x 118px` の中央クロップを初期値とする。

## 注意

- 距離はLCDではなく、カメラレンズから対象物までで測る。
- 対象物はカメラ面と平行に置く。
- 最初はレンズ歪みが少ない中央付近でピクセル数を数える。
- LCDには位置合わせ用に縦長クロップ表示しているが、保存BMPはクロップ前のカメラフレーム。
- ステータス表示は角丸で欠けないよう、左上端ではなく安全領域内に表示する。
- 起動時にSD初期化へ失敗した場合でも、Wakeボタン押下時にSD初期化を一度リトライする。
- 画面が左右反転している場合は、OV3660のセンサー設定で `hmirror` を調整する。
- 上下反転は実機確認済みのため、現在のファームでは `set_vflip(1)` で補正している。
- RGB565のbyte orderは、LCDライブ表示とBMP保存で分けて扱う。LCD表示は `low byte, high byte`、24bit BMP保存は `high byte, low byte` として展開する。

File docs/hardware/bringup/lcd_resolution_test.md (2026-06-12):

# Waveshare 1.83inch LCD Rev2 表示確認

## 目的

Waveshare 1.83inch LCD Module Rev2 / ST7789P の実機表示を確認し、VIDEO SIGHTで使用する表示領域、向き、色、角丸による欠け方を確定する。

## 対象

- MCU: Seeed Studio XIAO ESP32S3 Sense
- LCD: Waveshare 1.83inch LCD Module Rev2
- Controller: ST7789P
- 接続: `docs/hardware/parts_and_pinout.md` のLCD/SPIピンアサイン
- 確認プログラム:
  - `firmware/esp32s3/examples/lcd_resolution_test/`
  - 現行本体側の `firmware/esp32s3/src/main.cpp` にも同等のLCD確認コードを反映済み
- 確認Issue: <https://github.com/Kehaar38/video-sight/issues/6>

## 確認結果

- 表示解像度: `240 x 284`
- 使用向き: `rotation = 0`
- 表示オフセット: `offset = 0, 0`
- 白い外枠線: 4辺すべて表示される
- 色: 赤・緑・青・白の表示に違和感なし
- 角: LCD自体が角丸形状のため、四隅は物理的に欠ける
- 角丸の開始位置: 黄色い20px目盛りの2本目付近からカーブが始まるように見える

## 解釈

白い外枠線が4辺とも見えており、表示文字も `visible=240x284` / `panel=240x284` / `offset=0,0` と読めるため、Rev2の表示領域は仕様通り `240 x 284` と扱ってよい。

角の欠けは解像度・オフセット不整合ではなく、ディスプレイ形状によるものとして扱う。UIや照準表示では、重要情報を四隅の角丸領域へ置かない。

## ファームウェア設定値

```cpp
constexpr int LCD_WIDTH = 240;
constexpr int LCD_HEIGHT = 284;
constexpr int LCD_OFFSET_X = 0;
constexpr int LCD_OFFSET_Y = 0;
constexpr uint8_t LCD_PRODUCT_ROTATION = 0;
```

## UI設計メモ

角丸で欠ける四隅は安全領域外として扱う。少なくとも端から20px程度までは装飾・目盛り程度にとどめ、文字、照準、状態表示、重要なアイコンは内側へ寄せる。

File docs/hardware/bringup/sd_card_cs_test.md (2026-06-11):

# XIAO ESP32S3 Sense microSD CS確認

## 目的

XIAO ESP32S3 Sense のmicroSDカードスロットで使用する CS ピンを、実機テストで確定する。

Seeed Studio Wiki では、XIAO ESP32S3 Sense のmicroSD初期化例として `SD.begin(21)` が示されている一方、Round Display 利用時は `D2` を渡す旨の記述もある。VIDEO SIGHTでは、XIAO ESP32S3 Sense基板内蔵のmicroSDスロットを対象として確認した。

## 確認結果

- 対象: Seeed Studio XIAO ESP32S3 Sense
- 対象スロット: XIAO ESP32S3 Sense 基板内蔵microSDスロット
- microSD CS: `GPIO21`
- Arduino / PlatformIO 初期化: `SD.begin(21)`
- 実機確認: 初期化、ルートディレクトリ一覧、テストファイル書き込み、読み戻しに成功
- `D2/GPIO3` は VIDEO SIGHT のmicroSD CSとしては使用しない

## テストプログラム

保存場所:

```text
firmware/esp32s3/examples/sd_cs_test/
```

実行例:

```bash
cd firmware/esp32s3/examples/sd_cs_test
pio run
pio run -t upload
pio device monitor
```

`src/main.cpp` 冒頭の `SD_CS_PIN` を `21` または `3` に手動変更して比較できる。VIDEO SIGHTでは `21` が正。

```cpp
const int SD_CS_PIN = 21;
```

## 参考

- [Sense版のMicroSDカード | Seeed Studio Wiki](https://wiki.seeedstudio.com/ja/xiao_esp32s3_sense_filesystem/)

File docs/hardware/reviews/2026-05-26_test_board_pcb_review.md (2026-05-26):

# 2026-05-26 テストボードPCBレビュー

## 対象

ユーザー更新コミット:

```text
2c7cf45 テストボードPCBだいたい完成
```

確認したスクリーンショット:

```text
hardware/screenshots/20260526/スクリーンショット 2026-05-26 223218.png
hardware/screenshots/20260526/スクリーンショット 2026-05-26 223310.png
```

KiCad PCB:

```text
hardware/kicad/video_sight_test_board/video_sight_test_board.kicad_pcb
```

ユーザー側ではDRC通過済み。こちらの環境には `kicad-cli` が無いため、DRCの再実行はしていない。

## 全体判断

初回テストボードとして、かなり良い配置・配線になっている。

特に良い点:

- 100mm角程度の広い基板に、機能ブロックが分かれて配置されている。
- 電源・XIAO/LCD/BNO055・入力装置・ATtiny周りが視覚的に分かりやすい。
- テストポイントが多く、bring-up時に測定しやすい。
- GNDテストポイントが複数あり、オシロ/ロジアナを当てやすい。
- DRC通過済みで、初回発注前段階としてはかなり進んでいる。

現時点で大きなブロッカーは見つからない。

## PCB概要

PCBファイルから確認した概要:

```text
基板外形: 約 99.06mm x 99.06mm
部品数: 57 footprints相当
配線セグメント: 214
ビア: 73
ゾーン: 7
実装面: ほぼF.Cu側
MountingHole_3.2mm_M3: 4箇所、BOM/位置出力除外
```

## ブロック別レビュー

### XIAO / IDC / LCD周り

左上にXIAOブレイクアウト用IDCコネクタ `J2` とLCDヘッダ `J3` がまとまっている。LCDとXIAO間の配線が短く、テストボードとして良い。

確認したい点:

- `J2` のpin 1マーク、キー溝方向、ケーブル出口方向。
- ブレイクアウト基板側とストレートIDCケーブルで `pin N -> pin N` になること。
- LCDケーブルは逆挿し可能なので、少なくともpin 1側/向きのシルクを強くすること。

### 電源周り

左側にBattery, SW_BATT, AO3401A, BATT_CURRENT, TPS22919周辺がまとまっている。テストポイントも近く、測定しやすい。

良い点:

- `BAT+`, `BAT_SW`, `XIAO_BAT`, `XIAO_3V3`, `PERIPH_EN`, `PERIPH_3V3` が測りやすい。
- TPS22919周りのC1/C2/C3/C4が近く、意図が追いやすい。
- Q1 AO3401AとR1が近い。

確認したい点:

- Q1 AO3401AのSOT-23 pin 1向きと、実部品マーキング。
- TPS22919カスタムフットプリント `@自分用:DCK0006A_L` のpin 1位置とパッド番号。
- C3/C4が極性付き部品なら、シルクの `+`/`-` が実装時に十分分かるか。
- 電源系の配線幅が発注前の想定電流に対して十分か。

### BNO055周り

BNO055モジュールは左下寄りに配置され、近くに `RESET`, `INT`, `GND`, `2V8_OUT` のTPがある。bring-upでは扱いやすい。

確認したい点:

- BNO055モジュールの実物を挿した時、部品や周囲TPと干渉しないか。
- `2V8_OUT` は観測用で、給電入力に見えないようにする。
- IMUとして使うなら、最終筐体では周囲磁性体/電流経路との距離に注意する。今回のテストボードでは検証用として問題ない。

### ATtiny1616 / 入力装置周り

右側に入力ボタン、ロータリーエンコーダ、ATtiny1616、UPDI、VCCジャンパがまとまっている。サブMCU入力系のテストボードとして分かりやすい。

良い点:

- ATtinyの左右ヘッダがあり、実験・ジャンパがしやすい。
- UPDIヘッダと `ATTINY_VCC` ジャンパが近い。
- C8がATtiny VCC側にあり、以前の方針通り。
- WAKEボタンが追加されている。

確認したい点:

- SW3/SW4/SW5/SW6/SW7を実際に指で押した時、周囲コネクタや筐体と干渉しないか。
- ロータリーエンコーダSW7のノブ径、軸高、取り付けナット/ワッシャのクリアランス。
- J8とSW7の近さ。ケーブルを挿した状態でエンコーダ操作に支障がないか。

## 目視で気になった点

### 1. J2 IDCとLCDの向き表示

DRCでは見つからないが、実機で一番怖いのはコネクタ向き。

推奨:

```text
J2: pin 1、キー溝、ケーブル出口方向をシルクで明示
J3: LCD pin 1 / VCC / GND側をシルクで明示
```

### 2. 実装時のシルク重なり

全体的に見やすいが、部品密集部では実装後に隠れる文字がある。特にU1/TPS22919周辺、C3/C4周辺、J3/J2周辺は、組み立て後に値よりもネット名/向きが分かる方を優先したい。

### 3. GNDプレーンの分断

スクリーンショットでは中央〜右側に長めの配線があり、GNDゾーンが一部細く分断される可能性がある。DRCは通っているが、発注前にKiCadのゾーン塗りつぶし後表示で、GNDが島になっていないか確認する。

推奨:

```text
- GNDゾーンを再塗りつぶし
- unconnected island削除/確認
- GNDビアを必要に応じて追加
- LCD/SPI、ATtiny、電源周りの近くにGND returnがあるか確認
```

### 4. 電源配線幅

画像上では細すぎるようには見えないが、`BAT+`, `BAT_SW`, `XIAO_BAT`, `XIAO_3V3`, `PERIPH_3V3` は、信号線より太めにしておくのが安全。

特にLCDバックライトや周辺電源の瞬間電流を考え、電源経路は発注前にネットハイライトして確認する。

### 5. マウント穴と筐体

四隅のM3穴は良い。発注前に以下を確認する:

```text
- ネジ頭/スペーサが部品と干渉しないか
- 銅箔/シルク/配線が穴周辺に近すぎないか
- 将来の仮筐体で固定しやすい位置か
```

## 発注前チェックリスト

- [ ] KiCadでDRCを再実行し、警告も含めて確認する。
- [ ] ゾーンを再塗りつぶし、GND islandがないか確認する。
- [ ] J2 IDCの実ケーブルでキー方向とpin 1を確認する。
- [ ] J3 LCDケーブルの逆挿し対策/シルクを確認する。
- [ ] TPS22919 `DCK0006A_L` のpin 1、pad番号、パッケージ寸法をGerberで確認する。
- [ ] AO3401Aのpin 1/G/S/Dと実装向きをGerberで確認する。
- [ ] C3/C4が極性付きなら極性シルクを確認する。
- [ ] SW7ロータリーエンコーダの機械寸法、軸高、操作スペースを確認する。
- [ ] J8入力デバイスケーブルとSW7操作の干渉を確認する。
- [ ] Gerberビューアで全層を確認する。
- [ ] JLCPCB等へ投入する前に、ドリル、外形、スルーホール、シルク欠けを確認する。

## 追記: 2026-05-26 シルク追加確認

ユーザー更新コミット:

```text
91fc902 シルク追加
```

確認したスクリーンショット:

```text
hardware/screenshots/20260526/スクリーンショット 2026-05-26 230609.png
```

追加されたシルクにより、前回の弱点だったLCDコネクタとC3/C4の実装向きがかなり分かりやすくなった。

確認できた追加内容:

```text
J3 LCD:
  BL / RST / DC / CS / SCK / MOSI / GND / VCC の縦シルク追加

C3/C4:
  + 極性シルク追加
```

判断:

- LCDはpin機能が直接読めるようになり、逆挿し確認がしやすくなった。
- C3/C4は極性付き部品として実装する場合の向き確認がしやすくなった。
- `VCC` と `GND` がLCDヘッダ側で見えるようになったので、ケーブル接続前のテスター確認にも使いやすい。

残る注意点:

- LCD付属ケーブル自体は逆挿し可能なので、接続時は必ずLCD側pin順とJ3シルクを照合する。
- C3/C4の実部品マーキングと基板上の `+` が一致することを、Gerber/実装前に再確認する。
- IDCケーブルは入手済みとのことなので、ブレイクアウトボード設計時に実ケーブルでpin 1、キー方向、ケーブル出口方向を確認する。

## 結論

このPCBは、初回テストボードとして発注前段階に入ってよい完成度に見える。

残りは回路変更というより、発注前の物理確認:

```text
- コネクタ向き
- カスタムフットプリント
- 電源配線幅
- GNDゾーン
- 操作部品の機械干渉
- Gerber最終確認
```

を詰める段階。

特に `J2 IDC` と `TPS22919` は、動作不能につながりやすいので最後に重点確認する。

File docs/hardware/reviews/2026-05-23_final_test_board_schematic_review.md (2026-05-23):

# Final schematic review 2026-05-23 test-board draft

## Scope

Reviewed the final 2026-05-23 pushed schematic screenshots:

- battery / reverse-protection / ADC divider,
- XIAO breakout connector and I2C pull-up option,
- TPS22919 load switch,
- 1.89 inch LCD header,
- BNO055 IMU module header,
- ATtiny1616 sub-MCU and input-device wiring.

## Overall judgment

The schematic is in good shape for a first test-board draft.

The major earlier risks have been addressed:

- `PERIPH_EN` is separated from `XIAO_3V3`.
- GPIO41/D12 is routed through the breakout connector to `PERIPH_EN`.
- D6/GPIO43 is back to `LCD_BL`.
- SPI MOSI/MISO/SCK labels are distinct.
- ATtiny UPDI programming has a VCC isolation jumper.
- ATtiny local C8 decoupling is on the `UPDI_VCC` / ATtiny VCC side.
- I2C board-side pull-ups are present and marked optional/DNP in the schematic note.

## Block-by-block notes

### Battery / reverse protection

The battery block is clear:

```text
BATTERY -> BAT_CURRENT jumper -> SW_BATT -> AO3401A -> +BATT / XIAO_BAT
```

The battery ADC divider also looks appropriate:

```text
+BATT -> 470k -> BATT_ADC -> 220k -> GND
BATT_ADC -> 0.047uF -> GND
```

Keep the existing requirement: before PCB order, verify AO3401A symbol pin numbering against the chosen footprint and purchased part.

### XIAO breakout / I2C pull-ups

The XIAO breakout connector is readable and the pin mapping is now clear.

R7/R8 topology is correct:

```text
PERIPH_3V3 -> 4.7k -> I2C_SDA
PERIPH_3V3 -> 4.7k -> I2C_SCL
```

The text note says:

```text
R7/R8: optional I2C pull-ups to PERIPH_3V3
Default: DNP
Populate if module pull-ups are insufficient
```

This is the right policy. One KiCad/BOM detail: R7/R8 currently appear as normal populated parts (`dnp no`) in the schematic file. Before generating BOM/placement files, either set their KiCad DNP attribute or keep a clear manual BOM note.

### Load switch

The TPS22919 block is good:

```text
XIAO_3V3 -> TPS22919 IN
PERIPH_EN -> ON with 100k pulldown
TPS22919 OUT -> PERIPH_3V3
QOD -> 1k -> OUT
PERIPH_3V3 bulk/decoupling: 1uF + 47uF
```

This matches the intended low-power peripheral rail.

Before PCB order, verify the TPS22919 DCK footprint (`DCK0006A_N`) with the exact package/datasheet pinout.

### LCD

LCD header is straightforward:

```text
PERIPH_3V3, GND, SPI_MOSI, SPI_SCK, LCD_CS, LCD_DC, LCD_RST, LCD_BL
```

This matches the current allocation.

Note: if LCD_BL is a raw LED input rather than a logic/PWM enable input on the Waveshare module, confirm whether direct GPIO drive is acceptable or whether a transistor is needed. If the module already has a backlight driver/transistor, the current connection is fine.

### IMU / BNO055

The IMU header and test points look good:

```text
PERIPH_3V3, GND, I2C_SDA, I2C_SCL
IMU_2V8, IMU_INT, IMU_RESET test points
```

Keep `IMU_2V8` as observe-only unless the module documentation explicitly says otherwise.

### ATtiny1616 / inputs

The ATtiny block is good for a flexible test board:

- JP2 isolates ATtiny VCC / `UPDI_VCC` from `PERIPH_3V3`.
- C8 is on the MCU side of JP2.
- J4 exposes `UPDI_VCC`, GND, and PA0/UPDI through 470Ω.
- J5/J6 expose spare ATtiny pins for jumper experiments.
- J7 input device and switches use GND-return wiring with an internal pull-up note.

Recommended silkscreen/note near JP2/J4:

```text
Normal: JP2 closed, UPDI VCC is VREF only
Programmer power: JP2 open, power UPDI_VCC only
```

## Remaining pre-layout checks

Before moving to PCB/order, the main remaining work is mechanical/implementation detail rather than circuit concept:

1. Assign final footprints for all headers, test points, passives, switches, and connectors.
2. Set R7/R8 to KiCad DNP or explicitly exclude them in the first BOM.
3. Verify AO3401A and TPS22919 symbol/footprint pin mapping against datasheets.
4. Select keyed IDC connector footprints and confirm pin-1 orientation on both XIAO breakout and test board.
5. Decide LCD_BL electrical drive after checking the Waveshare LCD module backlight input.
6. Run KiCad ERC and review all NC markers/no-connect pins.
7. Add PCB silkscreen labels for power rails, jumper normal positions, UPDI warning, and connector pin 1.

## Summary

This is now a reasonable schematic baseline for the first VIDEO SIGHT test board.

No major schematic-level blocker is visible in the screenshots. The remaining risks are mostly:

- footprint/pinout mismatch,
- connector orientation,
- DNP/BOM handling for optional I2C pull-ups,
- LCD backlight drive confirmation.

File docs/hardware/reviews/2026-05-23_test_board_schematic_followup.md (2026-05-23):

# Schematic review follow-up 2026-05-23: XIAO breakout fixes

## Scope

Reviewed the pushed updates after the first 2026-05-23 test-board review:

- separated `PERIPH_EN` from the crowded `XIAO_3V3` area,
- added the XIAO ESP32-S3 breakout-board KiCad project,
- corrected the SPI label typo around MOSI/MISO,
- confirmed the intended GPIO41/D12 pad use for `PERIPH_EN`.

## Verified fixes

### `PERIPH_EN` / `XIAO_3V3`

The updated screenshot is much clearer.

Current intended layout:

```text
XIAO_3V3 -> TP5 -> C5 -> J2 pin 1
PERIPH_EN -> TP6 -> J2 pin 3
```

This resolves the previous visual shorting concern. The two nets are presented separately now.

### GPIO41 / D12 breakout mapping

The new breakout-board schematic maps:

```text
XIAO GPIO41_D12_MIC_DATA -> J1 pin 3
```

The test board uses:

```text
J2 pin 3 -> PERIPH_EN
```

So the intended chain is:

```text
XIAO GPIO41 / D12 pad -> breakout J1 pin 3 -> cable -> test-board J2 pin 3 -> PERIPH_EN -> TPS22919 ON
```

This matches the stated design.

### SPI labels

The visible label typo is fixed. The test-board side now distinguishes:

```text
SPI_MOSI
SPI_MISO
SPI_SCK
```

## Remaining checks before PCB layout

### Connector orientation / cable pin numbering

The main remaining risk is not the schematic net names, but the physical 2x10 connector orientation between the breakout board and test board.

Before layout/order, decide and document:

- whether the interconnect is pin-header to dupont wires, IDC ribbon, JST, or another connector,
- where pin 1 is on both boards,
- whether the cable crosses/mirrors the pinout,
- whether the mating footprints are viewed from the same side or opposite sides.

For the schematic, J1 pin 3 to J2 pin 3 is correct. The PCB/cable must preserve that mapping physically.

### Power/GND conductors

The connector has multiple useful return paths:

- J2 pin 2: GND
- J2 pin 19: GND
- J2 pin 20: +BATT
- J2 pin 1: XIAO_3V3

This is acceptable, but for a cable-mounted XIAO/camera assembly, keep ground conductors near power/high-speed signals if the connector/cable choice allows it.

### Footprints still need assignment

The connector footprint fields are still empty in the KiCad schematic for the test-board/breakout connectors. This is fine at schematic stage, but should be assigned before PCB placement and ERC/BOM review.

### Pending items unchanged

The following previously noted items still need a pass:

- ATtiny1616 UPDI/VCC/GND programming access,
- input-device pull-up assumptions,
- optional I2C pull-up footprints,
- BNO055 `IMU_RESET`, `IMU_INT`, and `IMU_2V8` handling.

## Summary

The three fixes are accepted:

- `PERIPH_EN` presentation is no longer visually confused with `XIAO_3V3`,
- GPIO41/D12 pad to `PERIPH_EN` is mapped through connector pin 3,
- SPI MOSI/MISO/SCK labels are separated.

The next highest-risk item is connector/cable orientation, because it can invalidate an otherwise-correct pin-to-pin schematic mapping.

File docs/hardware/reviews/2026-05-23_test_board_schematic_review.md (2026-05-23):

# Schematic review 2026-05-23: test-board update

## Scope

Reviewed the updated KiCad schematic and screenshots after:

- adding test points,
- replacing directly connected modules with headers/connectors,
- adding the XIAO breakout-board connector,
- exposing GPIO39-GPIO42 pads,
- moving `PERIPH_EN` from D6/GPIO43 to GPIO41/D12 pad,
- returning D6/GPIO43 to `LCD_BL`,
- making ATtiny1616 I/O available through jumpers.

## Good changes

- The test-point coverage is much better: battery input, switched battery, XIAO BAT, `XIAO_3V3`, `PERIPH_3V3`, `PERIPH_EN`, VBUS, SPI, and GND are visible.
- Header-based modules make sense for the large test board and temporary enclosure work.
- D6/GPIO43 returning to `LCD_BL` is useful; backlight PWM may become valuable during current/brightness testing.
- Using GPIO41/D12 pad for `PERIPH_EN` is a good direction if the XIAO breakout board makes the back-side pads easy to reach.
- ATtiny1616 I/O headers are appropriate for a test board; they keep button/encoder routing flexible.
- TPS22919 block still looks structurally correct: `XIAO_3V3` -> TPS22919 -> `PERIPH_3V3`, EN pulldown, QOD resistor, input/output capacitors.
- Battery block still looks structurally correct: battery -> current jumper -> switch -> AO3401A -> `+BATT`, with divider after protection.

## Issues / checks before layout

### 1. `PERIPH_EN` appears to be on the same wire as `XIAO_3V3` in the XIAO breakout screenshot

In the XIAO screenshot, the wire from the `XIAO_3V3` power symbol to J2 pin 1 also has the `PERIPH_EN` label and TP6 attached. If this is how the schematic is actually connected, `PERIPH_EN` is shorted to `XIAO_3V3`, which would keep TPS22919 always enabled and also drive the EN net from the 3.3V rail.

Expected:

- J2 pin for XIAO 3V3 should be only `XIAO_3V3`.
- `PERIPH_EN` should connect only to the intended GPIO41/D12 pad line plus TPS22919 ON and TP6.
- Do not put a power symbol and a signal label on the same wire unless the short is intentional.

### 2. Verify GPIO41 actually reaches `PERIPH_EN`

The stated intent is `GPIO41/D12 pad = PERIPH_EN`, but the screenshot does not clearly show a `GPIO41` net. Confirm in KiCad by highlighting `PERIPH_EN` and checking it lands on the GPIO41/D12 breakout pin, not on `XIAO_3V3` or GPIO42.

### 3. Check SPI labels on the XIAO breakout connector

The screenshot visually suggests two right-side pins may both be labeled `SPI_MOSI`. Since the current pinout expects SPI SCK/MISO/MOSI, verify the connector has the intended mapping:

- SPI_SCK
- SPI_MISO, if the test board needs it
- SPI_MOSI

The LCD needs SCK and MOSI; MISO may be unused by the LCD, but duplicated MOSI labels are a common source of layout mistakes.

### 4. ATtiny1616 needs an explicit UPDI programming path

ATtiny1616 uses PA0/RESET as UPDI. The PA0 pin is exposed on the right-side header, which can work, but add or clearly label a 3-pin programming header/test pads:

```text
UPDI / VCC / GND
```

This will make recovery and programming much easier on the test board.

### 5. ATtiny input devices rely on pull-ups

The buttons and rotary encoder common appear tied to GND. That is fine if firmware enables internal pull-ups on the ATtiny pins. Add a schematic note or optional pull-up footprints if uncertain.

### 6. I2C pull-ups are not obvious

BNO055 modules often include pull-ups, but the bus also includes ATtiny1616. Decide whether the test board should include optional I2C pull-up footprints, probably DNP by default:

```text
SDA -> 4.7k -> PERIPH_3V3
SCL -> 4.7k -> PERIPH_3V3
```

### 7. IMU_RESET / IMU_INT / IMU_2V8 should be intentional

The BNO055 header exposes `IMU_RESET`, `IMU_INT`, and `IMU_2V8`. If these are not used, mark them NC or route them to optional pads/jumpers. Do not accidentally drive a module's 2.8V output rail.

### 8. Connector footprints still need assignment

Several headers/connectors appear to have empty footprint fields. That is fine during schematic drafting, but assign footprints before PCB layout and before ERC/BOM review.

## Summary

The architecture is moving in a good direction for a test board. The main thing to check immediately is the `PERIPH_EN` net around the XIAO breakout connector: it should not be tied to `XIAO_3V3`, and it should clearly land on GPIO41/D12. After that, the next practical checks are UPDI access, optional I2C pull-ups, and connector footprints.

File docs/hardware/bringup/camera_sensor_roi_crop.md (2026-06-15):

# OV3660 センサー側ROIクロップ試行

## 目的

LCDに表示しない高解像度フレーム全体をESP32側で保持せず、OV3660センサー側で中央ROIだけを出力させる。

狙いは次の通り。

- LCD表示部分だけを扱う。
- VGA/XGAフレームから小さく切り出して拡大するモザイク感を避ける。
- QXGA/UXGA RGB565全体取得時の `capture failed` を避ける。
- SD保存もLCD表示範囲だけにする。

## 失敗した設定

最初に `240x284` の非標準・縦長ROIを試した。

```text
初期フレームサイズ: CIF 400x296
実出力: OV3660 set_res_raw() による 240x284
Pixel format: RGB565
LCD表示: 240x284 等倍
SD保存: 240x284 BMP
fb_count: 1
```

この設定では、シリアル上は次の通り `set_res_raw()` 自体は成功した。

```text
ROI crop active: start=(904,626) end=(1175,921) output=240x284 scale=0 binning=0
Camera ready: psram=yes fb_count=1 init_frame=CIF roi=240x284
```

しかし、その直後に `cam_task` のスタックカナリアで再起動した。

```text
Guru Meditation Error: Core 0 panic'ed (Unhandled debug exception).
Debug exception reason: Stack canary watchpoint triggered (cam_task)
```

そのため、`240x284` の非標準ROIは現時点では危険な設定として扱う。

## 現在の試行設定

次の切り分けとして、ESP32 camera定型サイズにもある `240x240` の正方形ROIへ下げる。

```text
初期フレームサイズ: FRAMESIZE_240X240
実出力: OV3660 set_res_raw() による 240x240
Pixel format: RGB565
LCD表示: 240x284 LCD中央に240x240を等倍表示、上下22pxは黒帯
SD保存: 240x240 BMP
fb_count: 1
```

この設定でライブビューが出れば、`set_res_raw()` による中心ROI出力そのものは使える可能性が高い。次に `320x320` や `240x284` 再調整へ進む。

## 実機確認結果

`240x240` ROI設定では、実機でライブビューが表示された。

確認できたこと:

- LCD表示が出る。
- 上下に黒帯が出る想定通りの表示になる。
- 目から約125mmでおおむね1倍に見える。
- VGA/XGA全体取得からのクロップ表示より、遅延が少なくキビキビ表示される体感がある。
- Wakeボタンで `240x240` の撮影保存ができる。

所感:

- 画質はサイトとして突き詰める段階ではない。
- 全体的に白飛び気味で、ノイズ混じりの低画質カメラのように見える。
- 後で露出・ゲイン・シャープネス・ノイズ低減などのセンサー設定を調整する候補がある。

確認用画像:

```text
dashboard-files/fov_0000_240x240.png
```

この結果から、`set_res_raw()` によるセンサー側ROI出力は有効な方向と判断する。

## ROIパラメータ

OV3660の1:1フル解像度設定は、esp32-cameraの `ratio_table` で次のようになっている。

```text
max_width/max_height: 1536 x 1536
sensor window: start=(256,0), end=(1823,1547)
offset: 16,6
total: 2044,1564
```

現在の試行では、この1:1中央領域の中にダミーマージンを含む `272x252` のタイミング窓を置き、出力を `240x240` にしている。

```text
start: 888,648
end:   1159,899
offset: 16,6
total: 2044,1564
output: 240 x 240
scale: false
binning: false
```

ファーム上では以下で設定する。

```cpp
sensor->set_res_raw(sensor,
  ROI_START_X, ROI_START_Y,
  ROI_END_X, ROI_END_Y,
  ROI_OFFSET_X, ROI_OFFSET_Y,
  ROI_TOTAL_X, ROI_TOTAL_Y,
  ROI_OUTPUT_WIDTH, ROI_OUTPUT_HEIGHT,
  ROI_SCALE, ROI_BINNING
);
```

## 確認項目

実機では次を確認する。

1. `ROI crop active` がシリアルに出るか。
2. `cam_task` のスタックカナリアで再起動しないか。
3. `camera capture failed` にならずライブビューが表示されるか。
4. `fb->width` / `fb->height` が期待通り `240x240` になるか。
5. 色順がこれまで通り正常か。
6. 画角が狭すぎる/広すぎる場合、ROI窓または出力サイズを調整する。
7. Wakeボタンで保存されるBMPが `240x240` になっているか。

## 注意

- `set_res_raw()` は定型 `set_framesize()` より低レベルの設定で、OV3660のレジスタ仕様・ドライバ実装に依存する。
- `240x284` の非標準・縦長出力は `set_res_raw()` 成功後に `cam_task` が落ちた。
- まず `240x240` の正方形ROIで、センサー側ROIの可否を切り分ける。
- `240x240` が成功した場合は、`320x320` ROIを取得してLCD中央の `240x284` を表示・保存する方法、または `240x284` パラメータの再調整を試す。
- センサー側ROIが安定した場合、FOV確認用exampleにも同じ方式を応用し、LCD表示範囲または指定ROIだけを保存する。

## 失敗した追加試行: 320x320 ROIから中央240x284表示

`240x240` ROIは実機で成功したため、次に `320x320` ROIを取得し、その中央 `240x284` だけをLCDへ等倍表示する試行を行った。

```text
初期フレームサイズ: CIF 400x296
実出力: OV3660 set_res_raw() による 320x320
LCD表示: 320x320の中央240x284を等倍表示
SD保存: 処理を簡単にするため、フレーム全体の320x320 BMP
fb_count: 1
```

この設定でも、`set_res_raw()` 自体は成功したが、実フレーム配送時に `cam_task` のスタックカナリアで再起動した。

```text
ROI crop active: start=(848,608) end=(1199,939) output=320x320 scale=0 binning=0
Camera ready: psram=yes fb_count=1 init_frame=CIF roi=320x320 lcd_crop=240x284
Guru Meditation Error: Core 0 panic'ed (Unhandled debug exception).
Debug exception reason: Stack canary watchpoint triggered (cam_task)
```

この結果から、`320x320` の非定型ROI出力も危険な設定として扱う。

## 次の試行: CIF 400x296 ROIから中央240x284表示

`240x240` は動作し、`240x284` と `320x320` は `cam_task` で落ちたため、次は定型サイズである `CIF 400x296` をセンサー側ROIとして出力した。

```text
初期フレームサイズ: CIF 400x296
実出力: OV3660 set_res_raw() による 400x296
LCD表示: 400x296の中央240x284を等倍表示
SD保存: 処理を簡単にするため、フレーム全体の400x296 BMP
fb_count: 1 -> 2へ変更して再試行
```

実機確認結果:

- LCD全体に中央 `240x284` が表示された。
- 見かけの大きさは `240x240` ROIと大きく変わらない。
- 撮影保存も元サイズ `400x296` で成功した。
- ただし、`240x240` ROIよりフレームレートが低く、もっさり感が戻った。

シリアル上の保存時間:

```text
Saved /fov/fov_0000_400x296.bmp in 885 ms
Saved /fov/fov_0001_400x296.bmp in 884 ms
```

このもっさり感の主因は、LCD中央クロップ処理そのものより、センサー出力が `240x240` から `400x296` へ増え、DVP転送とフレーム配送量が約2倍になったことだと考える。LCD表示の中央クロップは等倍切り出しのため、汎用スケーラではなく直接行コピーに近い処理へ最適化する。

ROIパラメータ:

```text
start: 824,620
end:   1255,927
offset: 16,6
total: 2300,1564
output: 400 x 296
scale: false
binning: false
```

LCD表示は中央を切り出す。

```text
source: 400 x 296
crop:   x=80, y=6, w=240, h=284
output: 240 x 284 LCDへ等倍表示
```

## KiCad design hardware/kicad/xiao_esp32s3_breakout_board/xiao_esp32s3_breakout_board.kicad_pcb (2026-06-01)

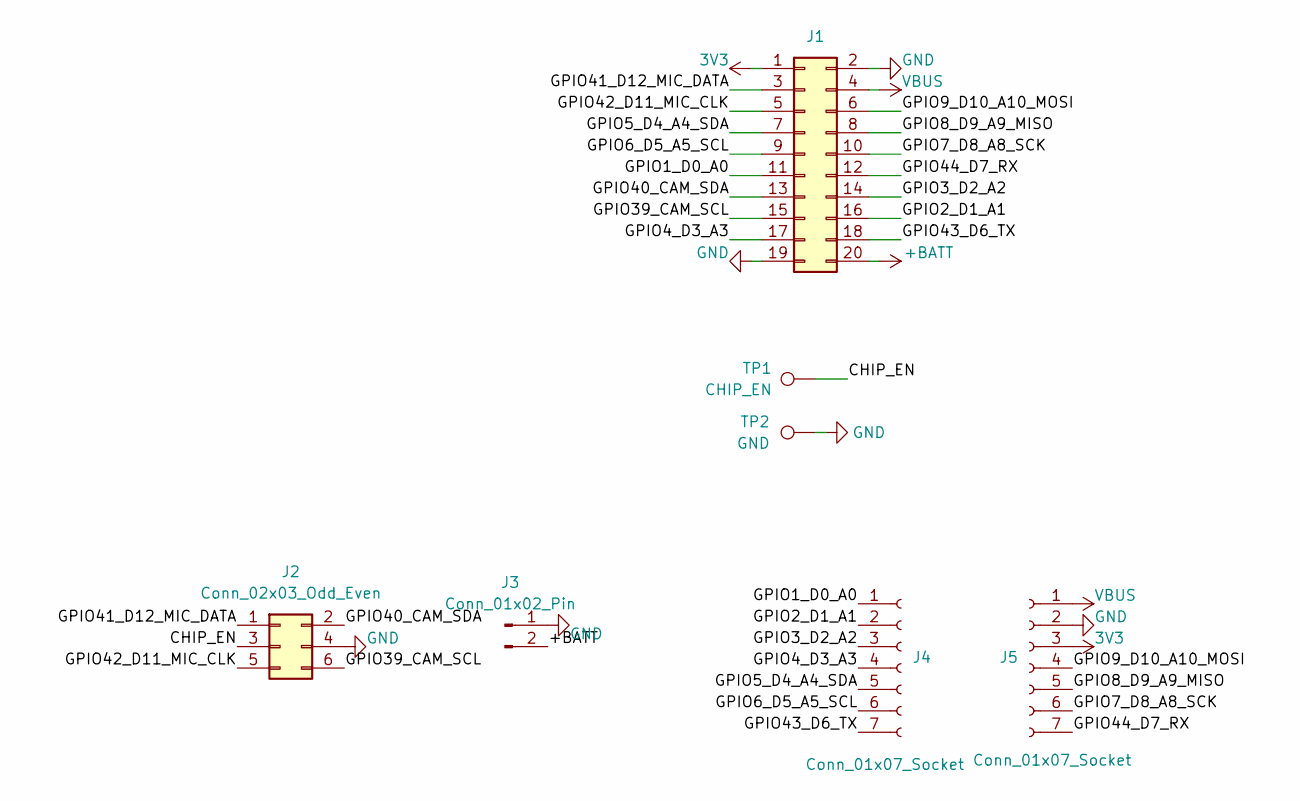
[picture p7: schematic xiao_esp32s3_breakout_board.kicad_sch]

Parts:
J1: XIAO_BREAKOUT_BOARD; IDC-Header_2x10_P2.54mm_Vertical
J2: Conn_02x03_Odd_Even; PinHeader_2x03_P2.54mm_Vertical
J3: Conn_01x02_Pin; PinHeader_1x02_P2.00mm_Vertical
J4, J5: Conn_01x07_Socket; PinSocket_1x07_P2.54mm_Vertical
TP1: CHIP_EN; TestPoint_THTPad_D1.5mm_Drill0.7mm
TP2: GND; TestPoint_THTPad_D1.5mm_Drill0.7mm

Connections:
3V3: J1.1, J5.3
+BATT: J1.20, J3.2
/CHIP_EN: J2.3, TP1.1
/GPIO1_D0_A0: J1.11, J4.1
/GPIO2_D1_A1: J1.16, J4.2
/GPIO3_D2_A2: J1.14, J4.3
/GPIO4_D3_A3: J1.17, J4.4
/GPIO5_D4_A4_SDA: J1.7, J4.5
/GPIO6_D5_A5_SCL: J1.9, J4.6
/GPIO7_D8_A8_SCK: J1.10, J5.6
/GPIO8_D9_A9_MISO: J1.8, J5.5
/GPIO9_D10_A10_MOSI: J1.6, J5.4
/GPIO39_CAM_SCL: J1.15, J2.6
/GPIO40_CAM_SDA: J1.13, J2.2
/GPIO41_D12_MIC_DATA: J1.3, J2.1
/GPIO42_D11_MIC_CLK: J1.5, J2.5
/GPIO43_D6_TX: J1.18, J4.7
/GPIO44_D7_RX: J1.12, J5.7
GND: J1.2, J1.19, J2.4, J3.1, J5.2, TP2.1
VBUS: J1.4, J5.1

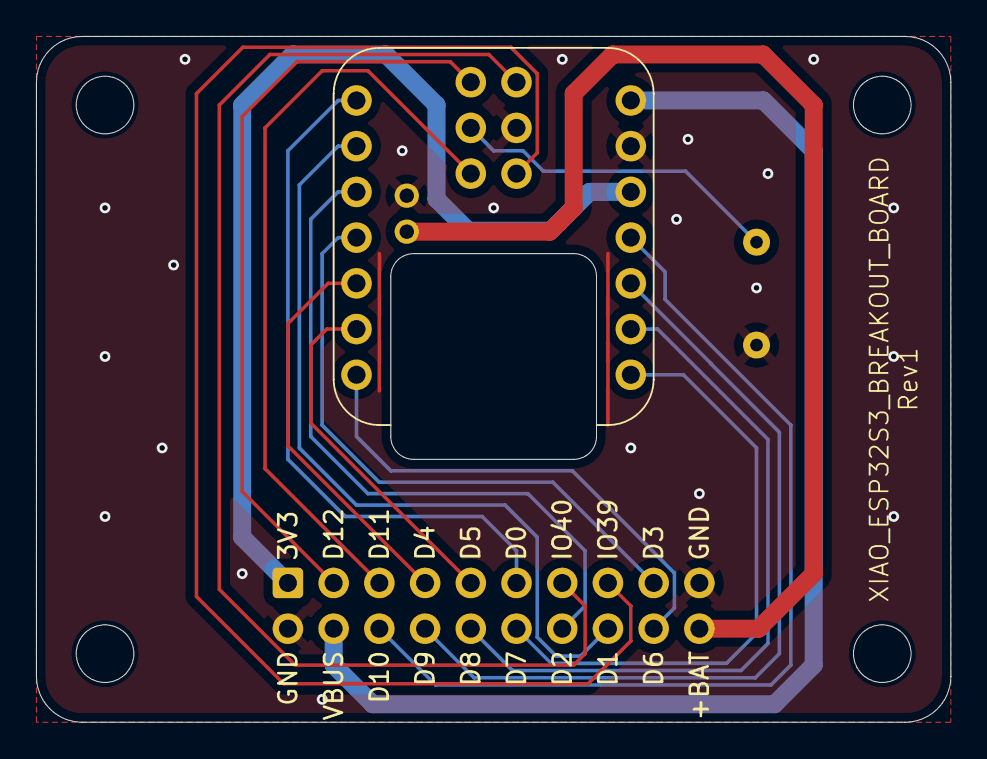
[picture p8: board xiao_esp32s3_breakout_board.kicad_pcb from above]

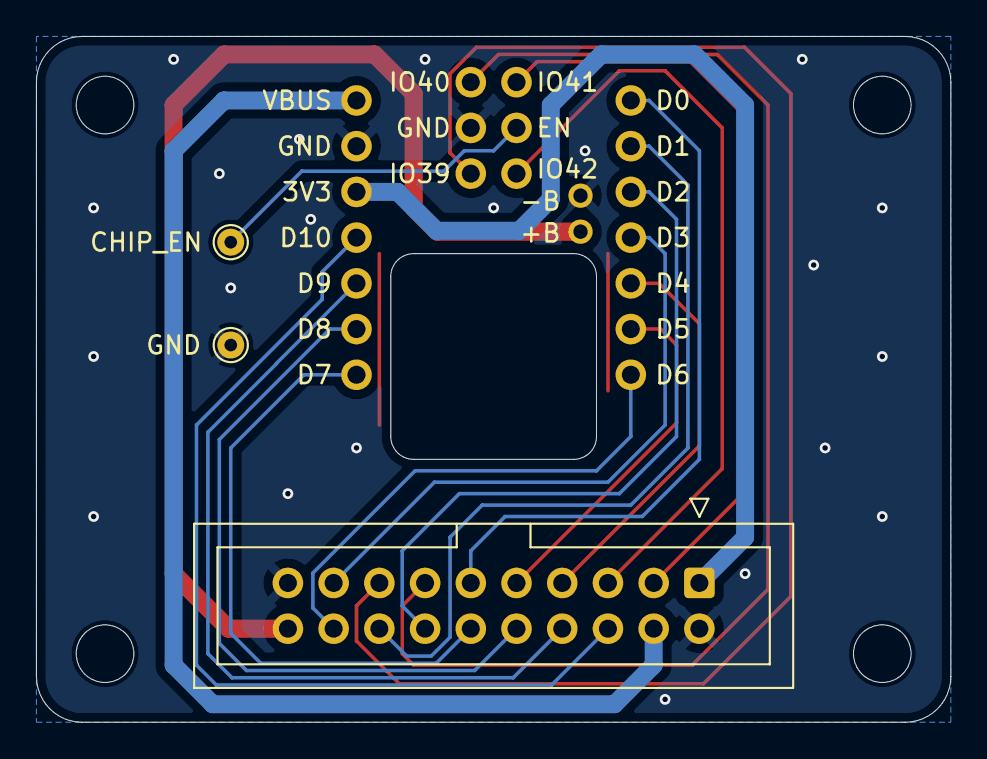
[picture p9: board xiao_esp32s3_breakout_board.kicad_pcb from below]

Board: 2 copper layers, 50.8 x 38.1 mm, 7 parts (3 on the bottom side), 20 nets.

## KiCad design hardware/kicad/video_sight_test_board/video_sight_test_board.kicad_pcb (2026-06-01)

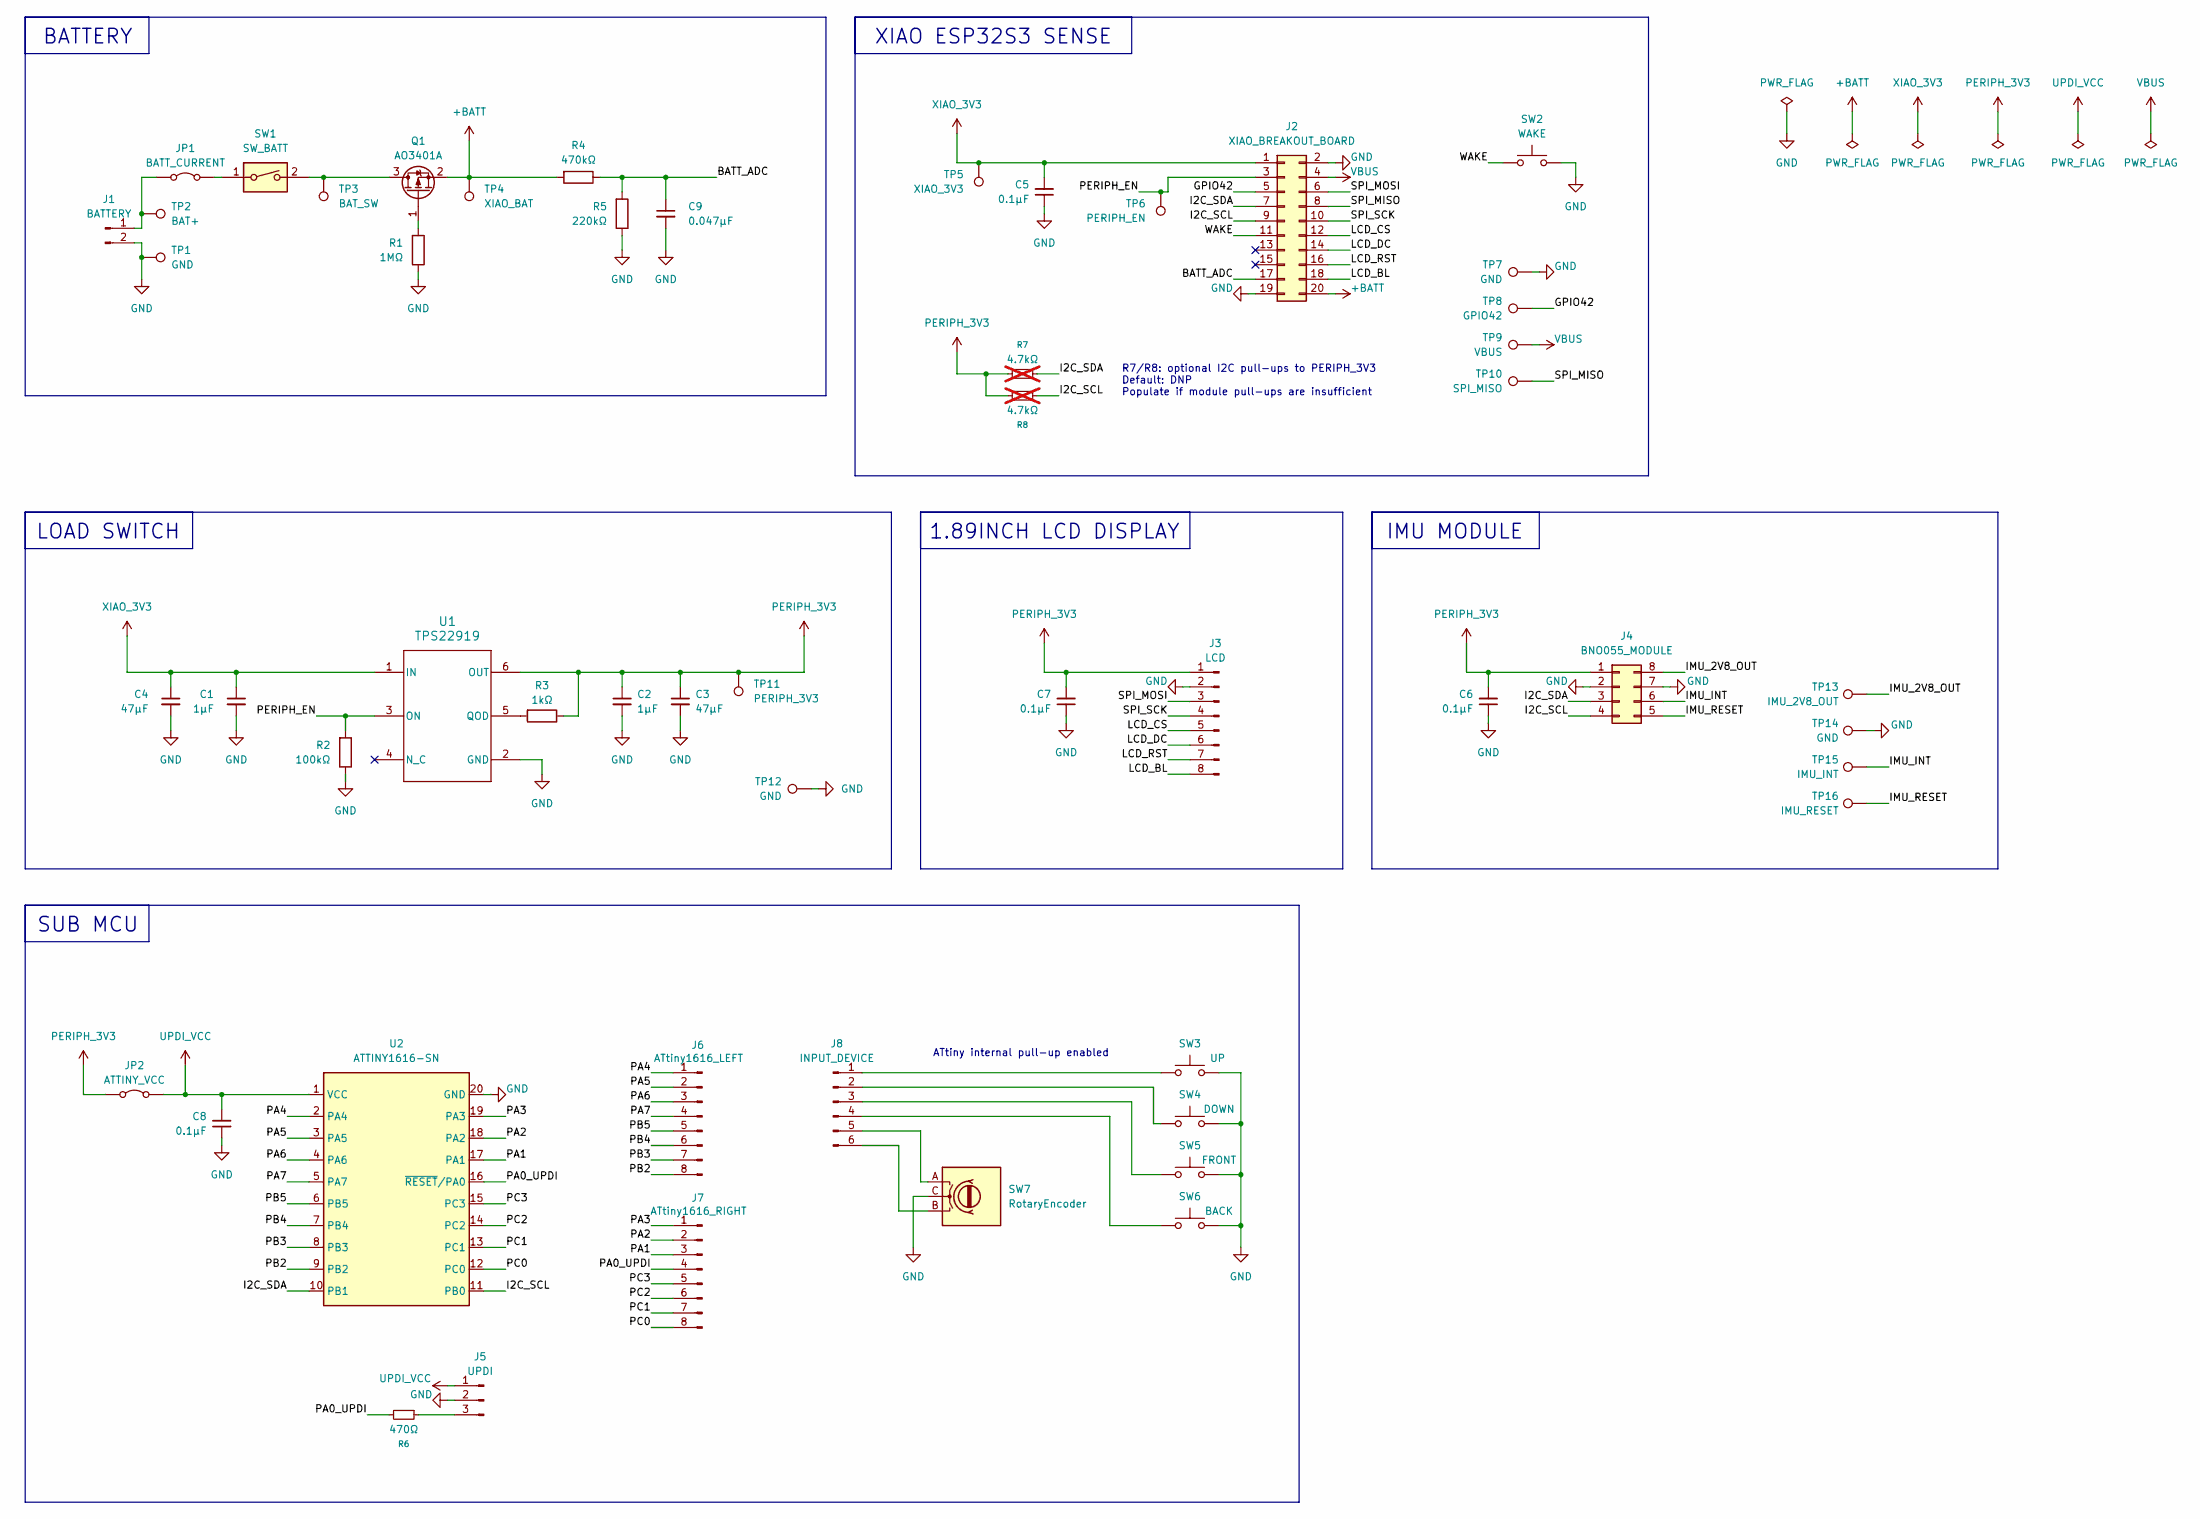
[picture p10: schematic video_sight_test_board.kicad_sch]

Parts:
C1, C2: 1μF; C_0805_2012Metric_Pad1.18x1.45mm_HandSolder
C3, C4: 47μF; CAP_FN_B_PAN
C5, C6, C7, C8: 0.1μF; C_0805_2012Metric_Pad1.18x1.45mm_HandSolder
C9: 0.047μF; C_0805_2012Metric_Pad1.18x1.45mm_HandSolder
J1: BATTERY; JST_XH_B2B-XH-A_1x02_P2.50mm_Vertical
J2: XIAO_BREAKOUT_BOARD; IDC-Header_2x10_P2.54mm_Vertical
J3: LCD; PinHeader_1x08_P2.54mm_Vertical
J4: BNO055_MODULE; DIP-8_W7.62mm_Socket
J5: UPDI; PinHeader_1x03_P2.54mm_Vertical
J6: ATtiny1616_LEFT; PinHeader_1x08_P2.54mm_Vertical
J7: ATtiny1616_RIGHT; PinHeader_1x08_P2.54mm_Vertical
J8: INPUT_DEVICE; PinHeader_1x06_P2.54mm_Vertical
JP1: BATT_CURRENT; PinHeader_1x02_P2.54mm_Vertical
JP2: ATTINY_VCC; PinHeader_1x02_P2.54mm_Vertical
Q1: AO3401A; SOT-23
R1: 1MΩ; R_0805_2012Metric_Pad1.20x1.40mm_HandSolder
R2: 100kΩ; R_0805_2012Metric_Pad1.20x1.40mm_HandSolder
R3: 1kΩ; R_0805_2012Metric_Pad1.20x1.40mm_HandSolder
R4: 470kΩ; R_0805_2012Metric_Pad1.20x1.40mm_HandSolder
R5: 220kΩ; R_0805_2012Metric_Pad1.20x1.40mm_HandSolder
R6: 470Ω; R_0805_2012Metric_Pad1.20x1.40mm_HandSolder
R7, R8: 4.7kΩ; R_0805_2012Metric_Pad1.20x1.40mm_HandSolder; not fitted
SW1: SW_BATT; SW_DIP_SPSTx01_Slide_9.78x4.72mm_W7.62mm_P2.54mm
SW2: WAKE; SW_PUSH_6mm
SW3: UP; SW_PUSH_6mm
SW4: DOWN; SW_PUSH_6mm
SW5: FRONT; SW_PUSH_6mm
SW6: BACK; SW_PUSH_6mm
SW7: RotaryEncoder; RotaryEncoder_Alps_EC12E_Vertical_H20mm
TP1, TP7, TP12, TP14: GND; TestPoint_THTPad_D1.5mm_Drill0.7mm
TP2: BAT+; TestPoint_THTPad_D1.5mm_Drill0.7mm
TP3: BAT_SW; TestPoint_THTPad_D1.5mm_Drill0.7mm
TP4: XIAO_BAT; TestPoint_THTPad_D1.5mm_Drill0.7mm
TP5: XIAO_3V3; TestPoint_THTPad_D1.5mm_Drill0.7mm
TP6: PERIPH_EN; TestPoint_THTPad_D1.5mm_Drill0.7mm
TP8: GPIO42; TestPoint_THTPad_D1.5mm_Drill0.7mm
TP9: VBUS; TestPoint_THTPad_D1.5mm_Drill0.7mm
TP10: SPI_MISO; TestPoint_THTPad_D1.5mm_Drill0.7mm
TP11: PERIPH_3V3; TestPoint_THTPad_D1.5mm_Drill0.7mm
TP13: IMU_2V8_OUT; TestPoint_THTPad_D1.5mm_Drill0.7mm
TP15: IMU_INT; TestPoint_THTPad_D1.5mm_Drill0.7mm
TP16: IMU_RESET; TestPoint_THTPad_D1.5mm_Drill0.7mm
U1: TPS22919; DCK0006A_L
U2: ATTINY1616-SN; SOIC-20W_7.5x12.8mm_P1.27mm

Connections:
+BATT: J2.20, Q1.2 (S), R4.2, TP4.1
/BATT_ADC: C9.1, J2.17, R4.1, R5.2
/GPIO42: J2.5, TP8.1
/I2C_SCL: J2.9, J4.4, R8.2, U2.11 (PB0)
/I2C_SDA: J2.7, J4.3, R7.2, U2.10 (PB1)
/IMU_2V8_OUT: J4.8, TP13.1
/IMU_INT: J4.6, TP15.1
/IMU_RESET: J4.5, TP16.1
/LCD_BL: J2.18, J3.8
/LCD_CS: J2.12, J3.5
/LCD_DC: J2.14, J3.6
/LCD_RST: J2.16, J3.7
/PA0_UPDI: J7.4, R6.2, U2.16 (~RESET/PA0)
/PA1: J7.3, U2.17 (PA1)
/PA2: J7.2, U2.18 (PA2)
/PA3: J7.1, U2.19 (PA3)
/PA4: J6.1, U2.2 (PA4)
/PA5: J6.2, U2.3 (PA5)
/PA6: J6.3, U2.4 (PA6)
/PA7: J6.4, U2.5 (PA7)
/PB2: J6.8, U2.9 (PB2)
/PB3: J6.7, U2.8 (PB3)
/PB4: J6.6, U2.7 (PB4)
/PB5: J6.5, U2.6 (PB5)
/PC0: J7.8, U2.12 (PC0)
/PC1: J7.7, U2.13 (PC1)
/PC2: J7.6, U2.14 (PC2)
/PC3: J7.5, U2.15 (PC3)
/PERIPH_EN: J2.3, R2.2, TP6.1, U1.3 (ON)
/SPI_MISO: J2.8, TP10.1
/SPI_MOSI: J2.6, J3.3
/SPI_SCK: J2.10, J3.4
/WAKE: J2.11, SW2.1
GND: C1.2, C2.2, C3.2, C4.2, C5.1, C6.1, C7.1, C8.1, C9.2, J1.2, J2.2, J2.19, J3.2, J4.2, J4.7, J5.2, R1.1, R2.1, R5.1, SW2.2, SW3.2, SW4.2, SW5.2, SW6.2, SW7.C, TP1.1, TP7.1, TP12.1, TP14.1, U1.2 (GND), U2.20 (GND)
unnamed: J1.1, JP1.1 (A), TP2.1
unnamed: J5.3, R6.1
unnamed: J8.1, SW3.1
unnamed: J8.2, SW4.1
unnamed: J8.3, SW5.1
unnamed: J8.4, SW6.1
unnamed: J8.5, SW7.A
unnamed: J8.6, SW7.B
unnamed: JP1.2 (B), SW1.1
unnamed: Q1.3 (D), SW1.2, TP3.1
unnamed: Q1.1 (G), R1.2
unnamed: R3.2, U1.5 (QOD)
PERIPH_3V3: C2.1, C3.1, C6.2, C7.2, J3.1, J4.1, JP2.1 (A), R3.1, R7.1, R8.1, TP11.1, U1.6 (OUT)
UPDI_VCC: C8.2, J5.1, JP2.2 (B), U2.1 (VCC)
VBUS: J2.4, TP9.1
XIAO_3V3: C1.1, C4.1, C5.2, J2.1, TP5.1, U1.1 (IN)

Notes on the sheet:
LOAD SWITCH
IMU MODULE
1.89INCH LCD DISPLAY
R7/R8: optional I2C pull-ups to PERIPH_3V3 Default: DNP Populate if module pull-ups are insufficient
XIAO ESP32S3 SENSE
SUB MCU
BATTERY
ATtiny internal pull-up enabled

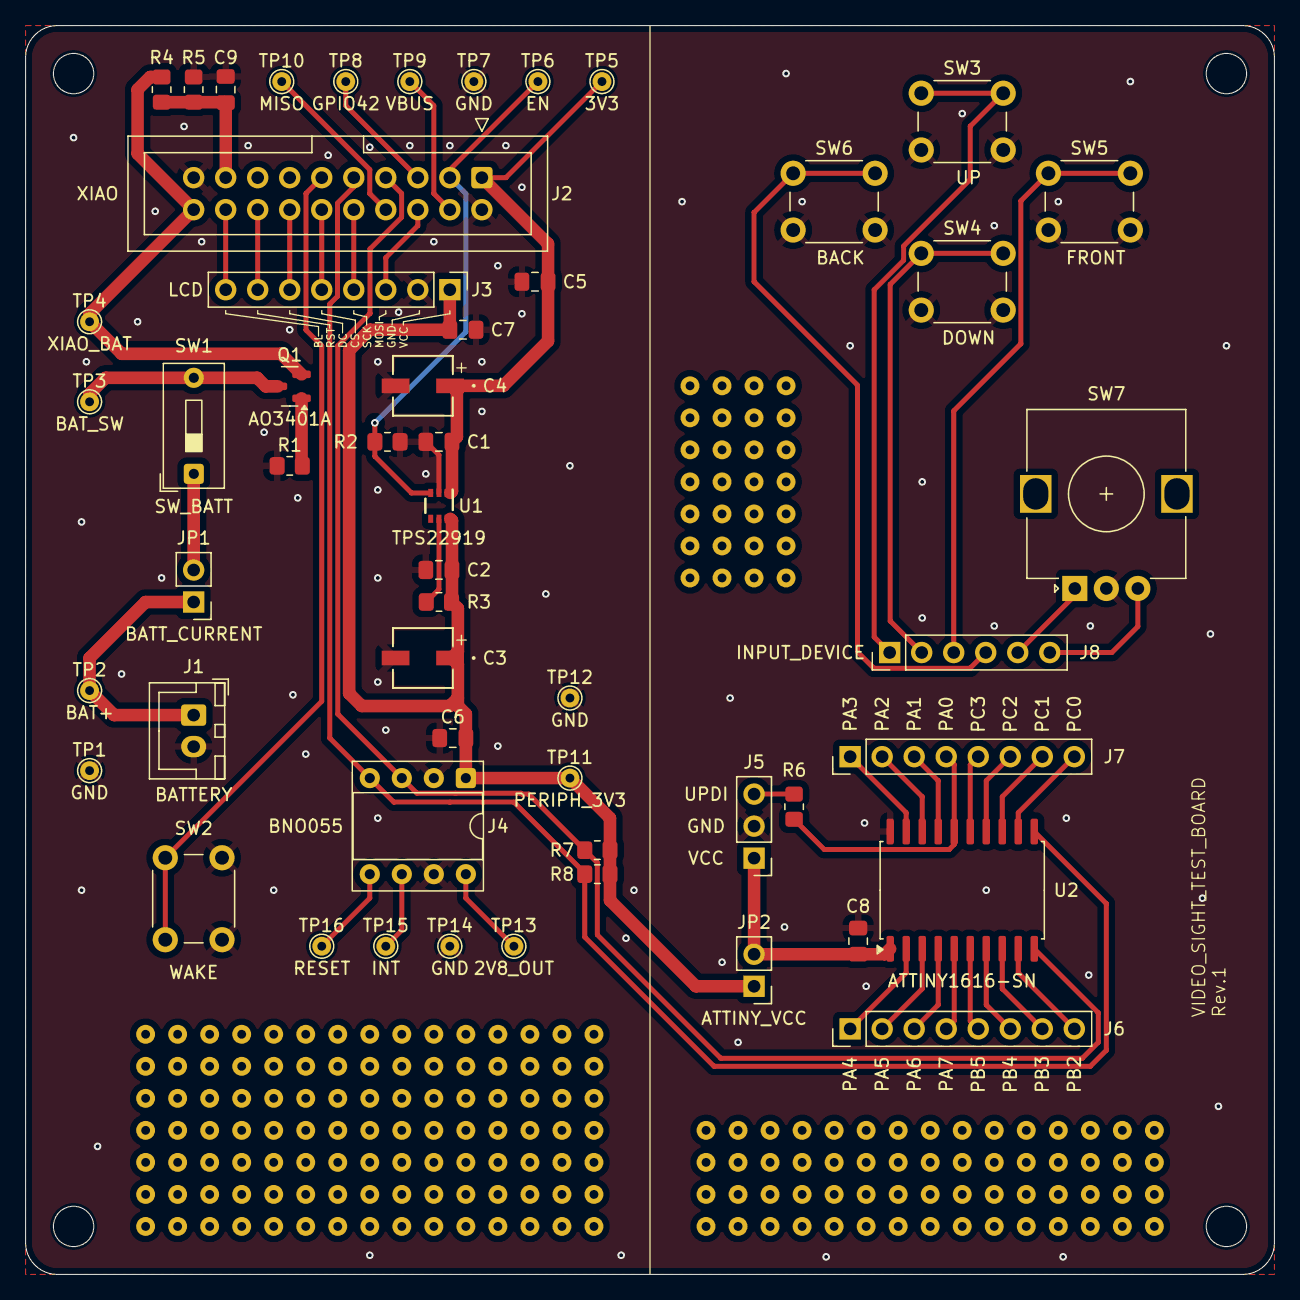
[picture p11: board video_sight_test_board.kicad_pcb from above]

Board: 2 copper layers, 99.1 x 99.1 mm, 53 parts (0 on the bottom side), 50 nets.

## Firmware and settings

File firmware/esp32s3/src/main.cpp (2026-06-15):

#include <Arduino.h>
#include <LovyanGFX.hpp>
#include "FS.h"
#include "SD.h"
#include <SPI.h>
#include "esp_camera.h"
#include "esp_heap_caps.h"

// VIDEO SIGHT camera live-view / FOV snapshot test.
// - LCD: Waveshare 1.83inch LCD Rev2 / ST7789P, 240x284, rotation 0.
// - Camera: XIAO ESP32S3 Sense bundled OV3660, DVP, RGB565 frame.
// - Wake button: D0 / GPIO1, active LOW. Press to save the current camera frame to SD.
// - SD: XIAO ESP32S3 Sense onboard microSD, CS GPIO21.
//
// The saved BMP is the camera-acquired ROI frame size. In the current ROI trial,
// the OV3660 is asked to output only a small center window.  The LCD shows a
// 240x284 center crop from that ROI without scaling.

namespace pins {
constexpr int WAKE_BUTTON = 1;

constexpr int LCD_RST = 2;
constexpr int LCD_DC = 3;
constexpr int LCD_BL = 43;
constexpr int LCD_CS = 44;
constexpr int SPI_SCK = 7;
constexpr int SPI_MISO = 8;
constexpr int SPI_MOSI = 9;
constexpr int SD_CS = 21;
constexpr int PERIPH_EN = 41;

// XIAO ESP32S3 Sense camera slot GPIO assignment from Seeed Wiki.
constexpr int CAM_XCLK = 10;
constexpr int CAM_SIOD = 40;
constexpr int CAM_SIOC = 39;
constexpr int CAM_Y9 = 48;
constexpr int CAM_Y8 = 11;
constexpr int CAM_Y7 = 12;
constexpr int CAM_Y6 = 14;
constexpr int CAM_Y5 = 16;
constexpr int CAM_Y4 = 18;
constexpr int CAM_Y3 = 17;
constexpr int CAM_Y2 = 15;
constexpr int CAM_VSYNC = 38;
constexpr int CAM_HREF = 47;
constexpr int CAM_PCLK = 13;
constexpr int CAM_PWDN = -1;
constexpr int CAM_RESET = -1;
}  // namespace pins

constexpr int LCD_WIDTH = 240;
constexpr int LCD_HEIGHT = 284;
constexpr int LCD_OFFSET_X = 0;
constexpr int LCD_OFFSET_Y = 0;
constexpr uint8_t LCD_PRODUCT_ROTATION = 0;

// Sensor-side ROI crop trial.  Instead of capturing a large frame and cropping
// it in ESP32 memory, ask the OV3660 to output only a small center window.
// Non-standard 240x284 and 320x320 ROI outputs configured successfully, but the
// camera task crashed before frames were delivered.  A 240x240 ROI worked.
// Next try the standard CIF output size (400x296), then show the center 240x284
// area on the LCD without scaling.  SD snapshots save the full 400x296 ROI
// because that is the simplest path with the existing frame-save routine.
constexpr int ROI_OUTPUT_WIDTH = 400;
constexpr int ROI_OUTPUT_HEIGHT = 296;
constexpr int LIVE_VIEW_CROP_WIDTH = LCD_WIDTH;
constexpr int LIVE_VIEW_CROP_HEIGHT = LCD_HEIGHT;
constexpr framesize_t CAMERA_FRAME_SIZE = FRAMESIZE_CIF;
constexpr pixformat_t CAMERA_PIXEL_FORMAT = PIXFORMAT_RGB565;
constexpr int JPEG_QUALITY_UNUSED_FOR_RGB565 = 12;

// OV3660 4:3 full-resolution timing from esp32-camera ratio_table uses
// start=(0,0), end=(2079,1547), offset=(16,6), total=(2300,1564).
// Center a 432x308 timing window, producing 400x296 after the offsets are
// removed.  The LCD then uses the center 240x284 without scaling.
constexpr int ROI_START_X = 824;
constexpr int ROI_START_Y = 620;
constexpr int ROI_END_X = 1255;
constexpr int ROI_END_Y = 927;
constexpr int ROI_OFFSET_X = 16;
constexpr int ROI_OFFSET_Y = 6;
constexpr int ROI_TOTAL_X = 2300;
constexpr int ROI_TOTAL_Y = 1564;
constexpr bool ROI_SCALE = false;
constexpr bool ROI_BINNING = false;

class VideoSightLcd : public lgfx::LGFX_Device {
  lgfx::Bus_SPI bus_;
  lgfx::Panel_ST7789 panel_;

 public:
  VideoSightLcd() {
    {
      auto cfg = bus_.config();
      cfg.spi_host = SPI2_HOST;
      cfg.spi_mode = 0;
      cfg.freq_write = 40000000;
      cfg.freq_read = 16000000;
      // LCDはDC線を持つ4線SPIとして扱う。SDと同じ物理SPIを共有するため、
      // MISOもバス設定に含めておく。
      cfg.spi_3wire = false;
      cfg.use_lock = true;
      cfg.dma_channel = SPI_DMA_CH_AUTO;
      cfg.pin_sclk = pins::SPI_SCK;
      cfg.pin_mosi = pins::SPI_MOSI;
      cfg.pin_miso = pins::SPI_MISO;
      cfg.pin_dc = pins::LCD_DC;
      bus_.config(cfg);
      panel_.setBus(&bus_);
    }

    {
      auto cfg = panel_.config();
      cfg.pin_cs = pins::LCD_CS;
      cfg.pin_rst = pins::LCD_RST;
      cfg.pin_busy = -1;
      cfg.memory_width = 240;
      cfg.memory_height = 320;
      cfg.panel_width = LCD_WIDTH;
      cfg.panel_height = LCD_HEIGHT;
      cfg.offset_x = LCD_OFFSET_X;
      cfg.offset_y = LCD_OFFSET_Y;
      cfg.offset_rotation = 0;
      cfg.dummy_read_pixel = 8;
      cfg.dummy_read_bits = 1;
      cfg.readable = false;
      cfg.invert = true;
      cfg.rgb_order = false;
      cfg.dlen_16bit = false;
      cfg.bus_shared = true;
      panel_.config(cfg);
    }

    setPanel(&panel_);
  }
};

VideoSightLcd lcd;
SPIClass sharedSpi(FSPI);
uint16_t *lcdLine = nullptr;
uint32_t captureIndex = 0;
uint32_t lastButtonChangeMs = 0;
bool lastButtonLevel = HIGH;
bool stableButtonLevel = HIGH;
bool sdReady = false;
bool cameraReady = false;

uint16_t readRgb565ForLcd(const uint8_t *p) {
  // LCD live viewは実機確認で low byte, high byte の順が正常だった。
  return (static_cast<uint16_t>(p[1]) << 8) | p[0];
}

uint16_t readRgb565ForBmp(const uint8_t *p) {
  // SDへ保存した24bit BMPは、LCD用と同じbyte orderでRGB888化すると
  // 疑似カラー状に崩れた。保存画像はカメラフレームの通常RGB565順で
  // high byte, low byte としてRGB888へ展開する。
  return (static_cast<uint16_t>(p[0]) << 8) | p[1];
}

void rgb565ToRgb888(uint16_t c, uint8_t &r, uint8_t &g, uint8_t &b) {
  r = ((c >> 11) & 0x1F) * 255 / 31;
  g = ((c >> 5) & 0x3F) * 255 / 63;
  b = (c & 0x1F) * 255 / 31;
}

void enablePeripheralRailAndBacklight() {
  pinMode(pins::PERIPH_EN, OUTPUT);
  digitalWrite(pins::PERIPH_EN, HIGH);
  delay(100);

  pinMode(pins::LCD_BL, OUTPUT);
  digitalWrite(pins::LCD_BL, HIGH);
}

bool initLcd() {
  pinMode(pins::LCD_CS, OUTPUT);
  digitalWrite(pins::LCD_CS, HIGH);

  if (!lcd.init()) {
    Serial.println("lcd.init() failed");
    return false;
  }

  lcd.setRotation(LCD_PRODUCT_ROTATION);
  lcd.setBrightness(255);
  lcd.fillScreen(TFT_BLACK);
  lcd.setTextColor(TFT_WHITE, TFT_BLACK);
  lcd.setCursor(24, 24);
  lcd.print("VIDEO SIGHT camera test");
  return true;
}

bool initSd(bool remount = false) {
  if (remount) {
    SD.end();
    delay(20);
  }

  pinMode(pins::SD_CS, OUTPUT);
  pinMode(pins::LCD_CS, OUTPUT);
  digitalWrite(pins::SD_CS, HIGH);
  digitalWrite(pins::LCD_CS, HIGH);

  // 添付の成功例と同じ考え方で、LCDとSDが同じSPIClassを使うようにする。
  // LovyanGFX側も同じSPI2/FSPIホスト・同じピンで設定している。
  sharedSpi.begin(pins::SPI_SCK, pins::SPI_MISO, pins::SPI_MOSI, pins::LCD_CS);

  if (!SD.begin(pins::SD_CS, sharedSpi, 4000000)) {
    Serial.println("SD.begin(21, sharedSpi, 4MHz) failed");
    digitalWrite(pins::SD_CS, HIGH);
    return false;
  }

  if (SD.cardType() == CARD_NONE) {
    Serial.println("No SD card attached");
    digitalWrite(pins::SD_CS, HIGH);
    return false;
  }

  if (!SD.exists("/fov")) {
    SD.mkdir("/fov");
  }

  digitalWrite(pins::SD_CS, HIGH);
  Serial.println("SD ready: /fov");
  return true;
}

bool applySensorRoiCrop(sensor_t *sensor) {
  if (!sensor || !sensor->set_res_raw) {
    Serial.println("ROI crop failed: set_res_raw unavailable");
    return false;
  }

  const int ret = sensor->set_res_raw(sensor, ROI_START_X, ROI_START_Y, ROI_END_X, ROI_END_Y,
                                      ROI_OFFSET_X, ROI_OFFSET_Y, ROI_TOTAL_X, ROI_TOTAL_Y,
                                      ROI_OUTPUT_WIDTH, ROI_OUTPUT_HEIGHT, ROI_SCALE, ROI_BINNING);
  if (ret != 0) {
    Serial.printf("ROI crop failed: set_res_raw ret=%d\n", ret);
    return false;
  }

  Serial.printf("ROI crop active: start=(%d,%d) end=(%d,%d) output=%dx%d scale=%d binning=%d\n",
                ROI_START_X, ROI_START_Y, ROI_END_X, ROI_END_Y, ROI_OUTPUT_WIDTH, ROI_OUTPUT_HEIGHT,
                ROI_SCALE ? 1 : 0, ROI_BINNING ? 1 : 0);
  return true;
}

bool initCamera() {
  camera_config_t config = {};
  config.ledc_channel = LEDC_CHANNEL_0;
  config.ledc_timer = LEDC_TIMER_0;
  config.pin_d0 = pins::CAM_Y2;
  config.pin_d1 = pins::CAM_Y3;
  config.pin_d2 = pins::CAM_Y4;
  config.pin_d3 = pins::CAM_Y5;
  config.pin_d4 = pins::CAM_Y6;
  config.pin_d5 = pins::CAM_Y7;
  config.pin_d6 = pins::CAM_Y8;
  config.pin_d7 = pins::CAM_Y9;
  config.pin_xclk = pins::CAM_XCLK;
  config.pin_pclk = pins::CAM_PCLK;
  config.pin_vsync = pins::CAM_VSYNC;
  config.pin_href = pins::CAM_HREF;
  config.pin_sccb_sda = pins::CAM_SIOD;
  config.pin_sccb_scl = pins::CAM_SIOC;
  config.pin_pwdn = pins::CAM_PWDN;
  config.pin_reset = pins::CAM_RESET;
  config.xclk_freq_hz = 20000000;
  config.pixel_format = CAMERA_PIXEL_FORMAT;
  config.frame_size = CAMERA_FRAME_SIZE;
  config.jpeg_quality = JPEG_QUALITY_UNUSED_FOR_RGB565;
  // CIF-sized ROI is small enough for double buffering. This lets the camera
  // capture the next frame while the current frame is being converted for LCD.
  config.fb_count = psramFound() ? 2 : 1;
  config.fb_location = psramFound() ? CAMERA_FB_IN_PSRAM : CAMERA_FB_IN_DRAM;
  config.grab_mode = CAMERA_GRAB_LATEST;

  esp_err_t err = esp_camera_init(&config);
  if (err != ESP_OK) {
    Serial.printf("esp_camera_init failed: 0x%x\n", err);
    return false;
  }

  sensor_t *sensor = esp_camera_sensor_get();
  if (!sensor) {
    Serial.println("esp_camera_sensor_get failed");
    return false;
  }

  sensor->set_framesize(sensor, CAMERA_FRAME_SIZE);
  if (!applySensorRoiCrop(sensor)) {
    return false;
  }

  // 実機確認で上下反転していたため、OV3660側で垂直反転を補正する。
  sensor->set_vflip(sensor, 1);
  sensor->set_hmirror(sensor, 0);

  Serial.printf("Camera ready: psram=%s fb_count=%d init_frame=CIF roi=%dx%d lcd_crop=%dx%d\n",
                psramFound() ? "yes" : "no", config.fb_count, ROI_OUTPUT_WIDTH,
                ROI_OUTPUT_HEIGHT, LIVE_VIEW_CROP_WIDTH, LIVE_VIEW_CROP_HEIGHT);
  return true;
}

void drawStatus(const char *message, uint16_t color = TFT_WHITE) {
  // Avoid rounded corners: the first visible characters can be clipped near x=0/y=0.
  constexpr int x = 24;
  constexpr int y = 24;
  lcd.fillRect(x - 4, y - 4, LCD_WIDTH - x, 18, TFT_BLACK);
  lcd.setTextColor(color, TFT_BLACK);
  lcd.setCursor(x, y);
  lcd.print(message);
}

void drawFrameToLcd(const camera_fb_t *fb) {
  if (!fb || fb->format != PIXFORMAT_RGB565 || !lcdLine) {
    return;
  }

  const int srcW = fb->width;
  const int srcH = fb->height;

  if (srcW == LCD_WIDTH && srcH <= LCD_HEIGHT) {
    const int dstY = (LCD_HEIGHT - srcH) / 2;
    lcd.startWrite();
    if (dstY > 0) {
      lcd.fillRect(0, 0, LCD_WIDTH, dstY, TFT_BLACK);
      lcd.fillRect(0, dstY + srcH, LCD_WIDTH, LCD_HEIGHT - dstY - srcH, TFT_BLACK);
    }
    for (int y = 0; y < srcH; ++y) {
      const uint8_t *srcRow = fb->buf + (y * srcW * 2);
      for (int x = 0; x < LCD_WIDTH; ++x) {
        lcdLine[x] = readRgb565ForLcd(srcRow + x * 2);
      }
      lcd.pushImage(0, dstY + y, LCD_WIDTH, 1, lcdLine);
    }
    lcd.endWrite();
  } else {
    const int cropW = min(LIVE_VIEW_CROP_WIDTH, srcW);
    const int cropH = min(LIVE_VIEW_CROP_HEIGHT, srcH);
    const int cropX = (srcW - cropW) / 2;
    const int cropY = (srcH - cropH) / 2;

    lcd.startWrite();
    if (cropW == LCD_WIDTH && cropH == LCD_HEIGHT) {
      // No-scale center crop path for CIF 400x296 -> LCD 240x284. Avoid the
      // per-pixel multiplication used by the generic scaler.
      for (int y = 0; y < LCD_HEIGHT; ++y) {
        const uint8_t *srcRow = fb->buf + ((cropY + y) * srcW + cropX) * 2;
        for (int x = 0; x < LCD_WIDTH; ++x) {
          lcdLine[x] = readRgb565ForLcd(srcRow + x * 2);
        }
        lcd.pushImage(0, y, LCD_WIDTH, 1, lcdLine);
      }
    } else {
      for (int y = 0; y < LCD_HEIGHT; ++y) {
        const int srcY = cropY + (y * cropH) / LCD_HEIGHT;
        const uint8_t *srcRow = fb->buf + (srcY * srcW * 2);
        for (int x = 0; x < LCD_WIDTH; ++x) {
          const int srcX = cropX + (x * cropW) / LCD_WIDTH;
          lcdLine[x] = readRgb565ForLcd(srcRow + srcX * 2);
        }
        lcd.pushImage(0, y, LCD_WIDTH, 1, lcdLine);
      }
    }
    lcd.endWrite();
  }

  // Simple safe-area and capture guide overlay. It is drawn after the frame so
  // the saved SD image remains raw camera data, not overlayed display data.
  lcd.drawRect(20, 20, LCD_WIDTH - 40, LCD_HEIGHT - 40, TFT_DARKGREY);
  lcd.drawFastHLine(0, LCD_HEIGHT / 2, LCD_WIDTH, TFT_DARKGREY);
  lcd.drawFastVLine(LCD_WIDTH / 2, 0, LCD_HEIGHT, TFT_DARKGREY);
}

bool writeBmp24FromRgb565Frame(const camera_fb_t *fb, const char *path) {
  if (!fb || fb->format != PIXFORMAT_RGB565) {
    Serial.println("save failed: frame is not RGB565");
    return false;
  }

  digitalWrite(pins::LCD_CS, HIGH);
  digitalWrite(pins::SD_CS, HIGH);

  File file = SD.open(path, FILE_WRITE);
  if (!file) {
    Serial.printf("failed to open %s\n", path);
    digitalWrite(pins::SD_CS, HIGH);
    return false;
  }

  const uint32_t width = fb->width;
  const uint32_t height = fb->height;
  const uint32_t rowSize = ((width * 3 + 3) / 4) * 4;
  const uint32_t pixelDataSize = rowSize * height;
  const uint32_t fileSize = 54 + pixelDataSize;

  uint8_t header[54] = {};
  header[0] = 'B';
  header[1] = 'M';
  header[2] = fileSize & 0xFF;
  header[3] = (fileSize >> 8) & 0xFF;
  header[4] = (fileSize >> 16) & 0xFF;
  header[5] = (fileSize >> 24) & 0xFF;
  header[10] = 54;
  header[14] = 40;
  header[18] = width & 0xFF;
  header[19] = (width >> 8) & 0xFF;
  header[20] = (width >> 16) & 0xFF;
  header[21] = (width >> 24) & 0xFF;
  header[22] = height & 0xFF;
  header[23] = (height >> 8) & 0xFF;
  header[24] = (height >> 16) & 0xFF;
  header[25] = (height >> 24) & 0xFF;
  header[26] = 1;
  header[28] = 24;
  header[34] = pixelDataSize & 0xFF;
  header[35] = (pixelDataSize >> 8) & 0xFF;
  header[36] = (pixelDataSize >> 16) & 0xFF;
  header[37] = (pixelDataSize >> 24) & 0xFF;

  if (file.write(header, sizeof(header)) != sizeof(header)) {
    file.close();
    digitalWrite(pins::SD_CS, HIGH);
    return false;
  }

  uint8_t *row = static_cast<uint8_t *>(malloc(rowSize));
  if (!row) {
    file.close();
    digitalWrite(pins::SD_CS, HIGH);
    Serial.println("save failed: row malloc");
    return false;
  }

  const uint32_t padding = rowSize - width * 3;
  for (int32_t y = height - 1; y >= 0; --y) {
    const uint8_t *src = fb->buf + y * width * 2;
    uint8_t *dst = row;
    for (uint32_t x = 0; x < width; ++x) {
      uint8_t r, g, b;
      rgb565ToRgb888(readRgb565ForBmp(src + x * 2), r, g, b);
      *dst++ = b;
      *dst++ = g;
      *dst++ = r;
    }
    for (uint32_t i = 0; i < padding; ++i) {
      *dst++ = 0;
    }
    if (file.write(row, rowSize) != rowSize) {
      free(row);
      file.close();
      digitalWrite(pins::SD_CS, HIGH);
      Serial.println("save failed: write row");
      return false;
    }
  }

  free(row);
  file.close();
  digitalWrite(pins::SD_CS, HIGH);
  return true;
}

bool saveCurrentFrameToSd(const camera_fb_t *fb) {
  if (!sdReady) {
    Serial.println("SD not ready; retrying SD init before save");
    drawStatus("Retry SD...", TFT_YELLOW);
    sdReady = initSd(true);
  }

  if (!sdReady) {
    drawStatus("SD not ready", TFT_RED);
    return false;
  }

  char path[48];
  snprintf(path, sizeof(path), "/fov/fov_%04lu_%ux%u.bmp",
           static_cast<unsigned long>(captureIndex++), fb->width, fb->height);

  Serial.printf("Saving %s ...\n", path);
  drawStatus("Saving BMP...", TFT_YELLOW);

  const uint32_t start = millis();
  const bool ok = writeBmp24FromRgb565Frame(fb, path);
  const uint32_t elapsed = millis() - start;

  if (ok) {
    Serial.printf("Saved %s in %lu ms\n", path, static_cast<unsigned long>(elapsed));
    drawStatus("Saved to /fov", TFT_GREEN);
  } else {
    Serial.printf("Save failed: %s\n", path);
    drawStatus("Save failed", TFT_RED);
  }
  return ok;
}

bool wakeButtonPressedEvent() {
  const bool level = digitalRead(pins::WAKE_BUTTON);
  const uint32_t now = millis();

  if (level != lastButtonLevel) {
    lastButtonLevel = level;
    lastButtonChangeMs = now;
  }

  if ((now - lastButtonChangeMs) < 40) {
    return false;
  }

  if (level != stableButtonLevel) {
    stableButtonLevel = level;
    if (stableButtonLevel == LOW) {
      return true;
    }
  }

  return false;
}

void setup() {
  Serial.begin(115200);
  delay(2000);

  Serial.println();
  Serial.println("========================================");
  Serial.println("VIDEO SIGHT - camera live view / FOV capture");
  Serial.println("Wake button: save current RGB565 camera frame as BMP to /fov");
  Serial.println("LCD: OV3660 sensor-side ROI CIF 400x296, center 240x284 no-scale crop");
  Serial.println("========================================");
  Serial.printf("PSRAM found: %s size=%u\n", psramFound() ? "yes" : "no",
                static_cast<unsigned>(ESP.getPsramSize()));

  pinMode(pins::WAKE_BUTTON, INPUT_PULLUP);
  enablePeripheralRailAndBacklight();

  lcdLine = static_cast<uint16_t *>(heap_caps_malloc(LCD_WIDTH * sizeof(uint16_t),
                                                      MALLOC_CAP_DMA | MALLOC_CAP_INTERNAL));
  if (!lcdLine) {
    lcdLine = static_cast<uint16_t *>(malloc(LCD_WIDTH * sizeof(uint16_t)));
  }

  const bool lcdReady = initLcd();
  cameraReady = initCamera();
  sdReady = initSd();

  if (!lcdLine) {
    Serial.println("lcdLine allocation failed");
    if (lcdReady) drawStatus("line buffer failed", TFT_RED);
  } else if (!cameraReady) {
    if (lcdReady) drawStatus("camera failed", TFT_RED);
  } else if (!sdReady) {
    if (lcdReady) drawStatus("SD failed", TFT_RED);
  } else {
    if (lcdReady) drawStatus("Live: D0 saves BMP", TFT_GREEN);
  }
}

void loop() {
  if (!cameraReady || !lcdLine) {
    delay(500);
    return;
  }

  camera_fb_t *fb = esp_camera_fb_get();
  if (!fb) {
    Serial.println("camera capture failed");
    drawStatus("capture failed", TFT_RED);
    delay(100);
    return;
  }

  drawFrameToLcd(fb);

  if (wakeButtonPressedEvent()) {
    saveCurrentFrameToSd(fb);
  }

  esp_camera_fb_return(fb);
}

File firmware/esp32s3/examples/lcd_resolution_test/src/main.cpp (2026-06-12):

#include <Arduino.h>
#include <LovyanGFX.hpp>

// VIDEO SIGHT LCD bring-up / resolution check.
// Target module: Waveshare 1.83inch LCD Module Rev2 / ST7789P / 240x284.
//
// Wiring from docs/hardware/parts_and_pinout.md:
//   LCD_RST  D1 / GPIO2
//   LCD_DC   D2 / GPIO3
//   LCD_BL   D6 / GPIO43
//   LCD_CS   D7 / GPIO44
//   SPI_SCK  D8 / GPIO7
//   SPI_MISO D9 / GPIO8  (LCD does not use MISO)
//   SPI_MOSI D10 / GPIO9
//   PERIPH_EN D12 / GPIO41 (TPS22919 peripheral rail enable)

namespace pins {
constexpr int LCD_RST = 2;
constexpr int LCD_DC = 3;
constexpr int LCD_BL = 43;
constexpr int LCD_CS = 44;
constexpr int SPI_SCK = 7;
constexpr int SPI_MOSI = 9;
constexpr int PERIPH_EN = 41;
}  // namespace pins

// Confirmed on VIDEO SIGHT test hardware:
//   visible area: 240 x 284
//   product orientation: rotation 0
//   offset: 0,0
// The physical LCD has rounded corners; do not place important UI elements in
// the extreme corners.
constexpr int LCD_WIDTH = 240;
constexpr int LCD_HEIGHT = 284;
constexpr int LCD_OFFSET_X = 0;
constexpr int LCD_OFFSET_Y = 0;
constexpr uint8_t LCD_PRODUCT_ROTATION = 0;

class VideoSightLcd : public lgfx::LGFX_Device {
  lgfx::Bus_SPI bus_;
  lgfx::Panel_ST7789 panel_;

 public:
  VideoSightLcd() {
    {
      auto cfg = bus_.config();
      cfg.spi_host = SPI2_HOST;
      cfg.spi_mode = 0;
      cfg.freq_write = 40000000;
      cfg.freq_read = 16000000;
      cfg.spi_3wire = true;
      cfg.use_lock = true;
      cfg.dma_channel = SPI_DMA_CH_AUTO;
      cfg.pin_sclk = pins::SPI_SCK;
      cfg.pin_mosi = pins::SPI_MOSI;
      cfg.pin_miso = -1;
      cfg.pin_dc = pins::LCD_DC;
      bus_.config(cfg);
      panel_.setBus(&bus_);
    }

    {
      auto cfg = panel_.config();
      cfg.pin_cs = pins::LCD_CS;
      cfg.pin_rst = pins::LCD_RST;
      cfg.pin_busy = -1;

      cfg.memory_width = 240;
      cfg.memory_height = 320;
      cfg.panel_width = LCD_WIDTH;
      cfg.panel_height = LCD_HEIGHT;
      cfg.offset_x = LCD_OFFSET_X;
      cfg.offset_y = LCD_OFFSET_Y;
      cfg.offset_rotation = 0;

      cfg.dummy_read_pixel = 8;
      cfg.dummy_read_bits = 1;
      cfg.readable = false;
      cfg.invert = true;
      cfg.rgb_order = false;
      cfg.dlen_16bit = false;
      cfg.bus_shared = true;

      panel_.config(cfg);
    }

    setPanel(&panel_);
  }
};

VideoSightLcd lcd;

uint16_t color565(uint8_t r, uint8_t g, uint8_t b) {
  return lcd.color565(r, g, b);
}

void enablePeripheralRailAndBacklight() {
  pinMode(pins::PERIPH_EN, OUTPUT);
  digitalWrite(pins::PERIPH_EN, HIGH);
  delay(100);

  pinMode(pins::LCD_BL, OUTPUT);
  digitalWrite(pins::LCD_BL, HIGH);
}

void drawCornerLabel(int x, int y, const char *label, uint16_t color) {
  lcd.fillRect(x, y, 28, 28, color);
  lcd.setTextColor(TFT_WHITE, TFT_BLACK);
  lcd.setCursor(x + 2, y + 31);
  lcd.print(label);
}

void drawResolutionPattern(uint8_t rotation) {
  lcd.setRotation(rotation);
  const int w = lcd.width();
  const int h = lcd.height();

  lcd.fillScreen(TFT_BLACK);

  // One-pixel outer border. If any side is missing, the configured resolution
  // or ST7789 offset is probably wrong.
  lcd.drawRect(0, 0, w, h, TFT_WHITE);
  lcd.drawRect(1, 1, w - 2, h - 2, TFT_DARKGREY);

  // Colored corner blocks make rotation and edge clipping easy to identify.
  drawCornerLabel(4, 4, "TL", TFT_RED);
  drawCornerLabel(w - 32, 4, "TR", TFT_GREEN);
  drawCornerLabel(4, h - 48, "BL", TFT_BLUE);
  drawCornerLabel(w - 32, h - 48, "BR", TFT_ORANGE);

  // Center crosshair and 20-pixel grid ticks for visible-area confirmation.
  const int cx = w / 2;
  const int cy = h / 2;
  lcd.drawFastHLine(0, cy, w, TFT_CYAN);
  lcd.drawFastVLine(cx, 0, h, TFT_CYAN);

  for (int x = 0; x < w; x += 20) {
    lcd.drawFastVLine(x, 0, 8, TFT_YELLOW);
    lcd.drawFastVLine(x, h - 8, 8, TFT_YELLOW);
  }
  for (int y = 0; y < h; y += 20) {
    lcd.drawFastHLine(0, y, 8, TFT_YELLOW);
    lcd.drawFastHLine(w - 8, y, 8, TFT_YELLOW);
  }

  lcd.setTextColor(TFT_WHITE, TFT_BLACK);
  lcd.setTextSize(1);
  lcd.setCursor(38, 8);
  lcd.print("VIDEO SIGHT LCD TEST");
  lcd.setCursor(38, 22);
  lcd.printf("rotation=%u", rotation);
  lcd.setCursor(38, 36);
  lcd.printf("visible=%dx%d", w, h);
  lcd.setCursor(38, 50);
  lcd.printf("panel=%dx%d", LCD_WIDTH, LCD_HEIGHT);
  lcd.setCursor(38, 64);
  lcd.printf("offset=%d,%d", LCD_OFFSET_X, LCD_OFFSET_Y);

  lcd.setCursor(20, cy + 10);
  lcd.print("Check full white border");
  lcd.setCursor(20, cy + 24);
  lcd.print("and all 4 corner blocks");

  Serial.printf("rotation=%u width=%d height=%d offset=(%d,%d)\n", rotation, w, h,
                LCD_OFFSET_X, LCD_OFFSET_Y);
}

void drawColorCycleFrame(uint16_t color, const char *name) {
  lcd.fillScreen(color);
  lcd.setTextColor(TFT_WHITE, color);
  lcd.setTextSize(2);
  lcd.setCursor(20, 20);
  lcd.print(name);
  lcd.setTextSize(1);
  lcd.setCursor(20, 52);
  lcd.print("Color fill test");
  Serial.print("color fill: ");
  Serial.println(name);
}

void setup() {
  Serial.begin(115200);
  delay(2000);

  Serial.println();
  Serial.println("========================================");
  Serial.println("VIDEO SIGHT - LCD resolution test");
  Serial.println("Waveshare 1.83inch LCD Rev2 / ST7789P");
  Serial.println("Expected visible resolution: 240x284");
  Serial.println("========================================");

  enablePeripheralRailAndBacklight();

  if (!lcd.init()) {
    Serial.println("lcd.init() failed");
    return;
  }

  lcd.setBrightness(255);
  drawResolutionPattern(LCD_PRODUCT_ROTATION);
}

void loop() {
  static uint32_t last = 0;
  static uint8_t step = 0;

  if (millis() - last < 3500) {
    delay(10);
    return;
  }
  last = millis();

  switch (step % 8) {
    case 0:
      drawResolutionPattern(0);
      break;
    case 1:
      drawResolutionPattern(1);
      break;
    case 2:
      drawResolutionPattern(2);
      break;
    case 3:
      drawResolutionPattern(3);
      break;
    case 4:
      drawColorCycleFrame(TFT_RED, "RED");
      break;
    case 5:
      drawColorCycleFrame(TFT_GREEN, "GREEN");
      break;
    case 6:
      drawColorCycleFrame(TFT_BLUE, "BLUE");
      break;
    case 7:
      drawColorCycleFrame(TFT_WHITE, "WHITE");
      break;
  }

  step++;
}

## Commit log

2026-05-21 KiCADファイル新規追加
    [video_sight_test_board.kicad_pcb, video_sight_test_board.kicad_sch]
2026-05-21 issue #1 #3 #4 対応
    [video_sight_test_board.kicad_sch]
2026-05-21 XIAO ネットラベル追加 電流測定ジャンパー追加 PERIPH/XIAOバルクコンデンサ追加
    [video_sight_test_board.kicad_sch]
2026-05-21 KiCAD一時ファイル除外
2026-05-21 回路図スクリーンショット
2026-05-21 Add XIAO breakout board notes
2026-05-23 ディレクトリ名修正
2026-05-23 回路図更新
    [video_sight_test_board.kicad_sch]
2026-05-23 Review updated test-board schematic
2026-05-23 XIAO ESP32S3 ブレイクアウトボード作成
    [xiao_esp32s3_breakout_board.kicad_pcb, xiao_esp32s3_breakout_board.kicad_sch]
2026-05-23 テストボード回路図修正 SPI_MOSI 体裁
    [video_sight_test_board.kicad_sch]
2026-05-23 Review XIAO breakout schematic fixes
2026-05-23 IMU未使用ピン TP追加 他
    [video_sight_test_board.kicad_sch]
2026-05-23 Add ATtiny1616 UPDI programming power notes
2026-05-23 UPDI書き込み端子追加 内部プルアップ注記追加
    [video_sight_test_board.kicad_sch]
2026-05-23 Review ATtiny UPDI and IMU schematic updates
2026-05-23 Clarify IMU update added test points
2026-05-23 テストボード回路図修正 I2Cプルアップ追加 C8位置修正
    [video_sight_test_board.kicad_sch]
2026-05-23 Review C8 and I2C pull-up updates
2026-05-23 リファレンス修正
    [video_sight_test_board.kicad_sch]
2026-05-23 I2Cプルアップ注記追加
    [video_sight_test_board.kicad_sch]
2026-05-23 Add final test-board schematic review
2026-05-23 Add test point footprint notes
2026-05-24 フットプリント選定 微修正
    [video_sight_test_board.kicad_sch]
2026-05-24 Review footprint selection
2026-05-24 Document footprint and cable follow-up decisions
2026-05-24 WAKEスイッチ追加 TP10修正
    [video_sight_test_board.kicad_sch]
2026-05-24 Update test-board BOM after ERC fixes
2026-05-24 PCB途中
    [video_sight_test_board.kicad_pcb]
2026-05-25 PCBざっくり置いた
    [video_sight_test_board.kicad_pcb, video_sight_test_board.kicad_sch]
2026-05-26 テストボードPCBだいたい完成
    [video_sight_test_board.kicad_pcb]
2026-05-26 テストボードPCBレビューを追加
2026-05-26 シルク追加
    [video_sight_test_board.kicad_pcb]
2026-05-26 PCBシルク追加確認を追記
2026-05-27 ブレイクアウトボード作成中
    [xiao_esp32s3_breakout_board.kicad_pcb, xiao_esp32s3_breakout_board.kicad_sch]
2026-05-28 初期弾道予測モデルを文書化
2026-05-29 プロットシミュレーション作成
    [プロットシミュレーション.xlsx]
2026-06-01 これで注文した
    [bom.csv, designators.csv, positions.csv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]
2026-06-10 PlatformIO初期化
2026-06-11 SD CS確認用テストを追加
2026-06-11 SD CSテストをexamplesへ退避
2026-06-11 LCD解像度確認テストを追加
2026-06-11 解像度テスト
2026-06-12 LCD表示確認結果を反映
2026-06-12 カメラFOV撮影テストを追加
2026-06-12 カメラ表示の色と上下反転を補正
2026-06-12 カメラ撮影テストのSD初期化を改善
2026-06-13 LovyanGFXの共有SPI設定を調整
2026-06-14 BMP保存時のRGB565色変換を修正
2026-06-14 カメラFOV実測値を1倍クロップへ反映
2026-06-14 1倍表示の想定視距離を150mmへ変更
2026-06-14 QXGA等倍クロップを試行
2026-06-14 QXGA失敗を受けUXGAクロップへ戻す
2026-06-14 UXGA失敗を受けXGAクロップへ下げる
2026-06-15 FOV確認用スケッチをexampleへ退避
2026-06-15 OV3660センサー側ROIクロップを試行
2026-06-15 ROI試行を240x240へ切り分け
2026-06-15 240x240 ROI実機確認結果を記録
2026-06-15 320x320 ROI中央表示を試行
2026-06-15 320x320 ROI失敗を受けCIF ROIを試行
2026-06-15 CIF ROI表示経路を軽量化
